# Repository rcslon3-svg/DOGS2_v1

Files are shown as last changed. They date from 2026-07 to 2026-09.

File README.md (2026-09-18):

# DOGS²

**DOGS² (Dual Output Generator Supply Station)** is an open-source, standalone
board bring-up station. It combines two programmable power outputs, current and
voltage monitoring, a signal generator, and common embedded-interface tools in
one compact instrument.

It is powered from USB Type-C or an external voltage of 5–90 V, with an output voltage of 1–48 V and a peak current of up to 5 amperes. Power anything from anything.

<p align="center">
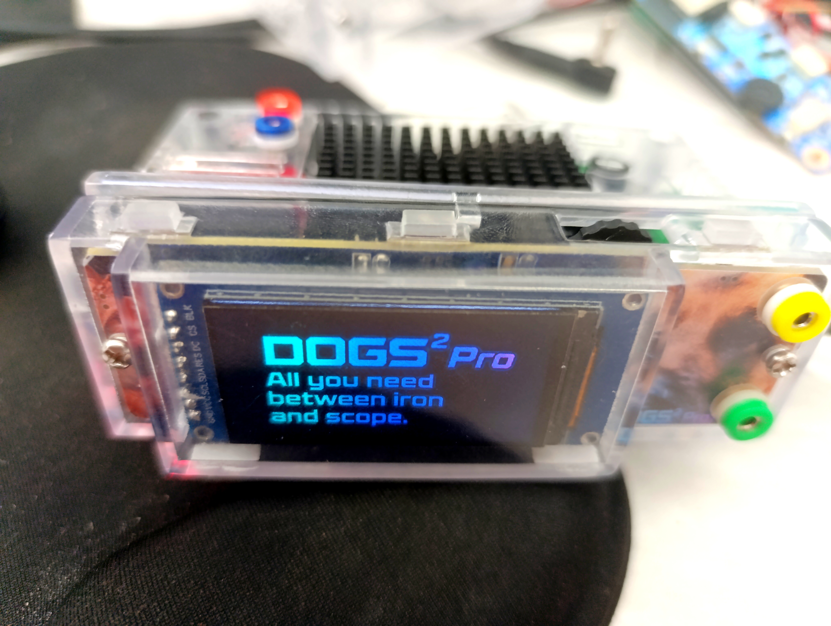
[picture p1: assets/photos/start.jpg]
DOGS² v1 welcome screen
  
</p>

<p align="center">
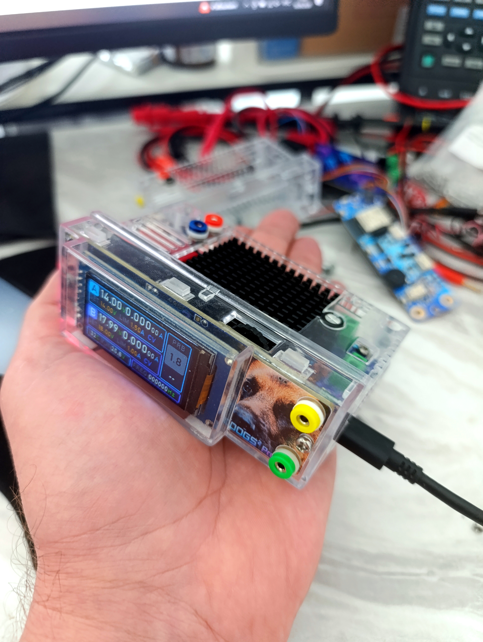
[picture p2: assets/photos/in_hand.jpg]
DOGS² v1 working engineering prototype
  
</p>

- DC/DC power channel 1-48V / 5A peak with CV/CC/OCP Shutdown operation, 50 uA current resolution;
- LDO power channel 1.3-20V / 2A peak with CV/CC/OCP Shutdown operation, 12.5 uA current resolution;
- actual values voltage and current monitoring;
- current graphics on display and phone app
- square-wave generator 1Hz - 100 kHz with 3-20V output voltage;
- UART and RS485 terminal modes;
- CAN receive, filtering, and transmission;
- LIN bus sniffer;
- I2C sniffer and I2C master terminal;
- logic probe and frequency meter input;
- standalone TFT display, encoder, and front-panel controls;
- Bluetooth SPP terminal data, command and telemetry (current graph) connection.

<p align="center">
  <strong><a href="https://dogs2.smartmoto.asia">Visit the DOGS² project website</a></strong><br>
  Project overview, beta-testing signup, and launch updates<br>
  <a href="https://hackaday.io/project/206311-dogs-dual-output-generator-supply-station">Follow the development logs on Hackaday.io</a>
</p>

This repository documents the current **v1 engineering samples**. The hardware
works and the firmware is under active development and tuning; published limits
and accuracy figures should therefore be treated as engineering-sample data,
not final product specifications.

## Project status

Five v1 engineering samples have been assembled. Hardware characterization,
firmware development, documentation, preparation for
external beta testing are ongoing.

**Want to follow or test DOGS²?** Visit the
[project website](https://dogs2.smartmoto.asia) for the overview and beta-test
signup, and follow the
[development logs on Hackaday.io](https://hackaday.io/project/206311-dogs-dual-output-generator-supply-station)
for build updates, tests, limitations, and design progress.

## Known issues the Engineering samples

Here is some known issues - read the files in directories Hardware and Mechanical.

## Repository structure

| Directory | Contents |
|---|---|
| [`hardware/`](hardware/) | Schematics, block diagram, editable design archive, PCB manufacturing files, BOMs, renders, and hardware known issues |
| [`mechanical/`](mechanical/) | Mechanical-design status and future enclosure files |
| [`software/`](software/) | Current ESP32 firmware, build configuration, tools, software documentation, and software known issues |

## Current capabilities

<p align="center">
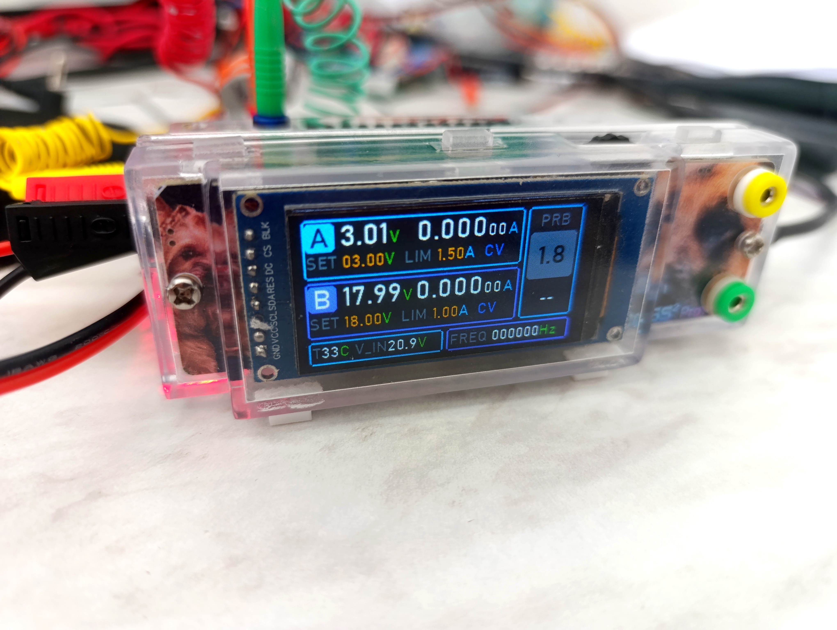
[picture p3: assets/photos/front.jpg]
DOGS² v1 connect and control
  
</p>

## Working hardware

<table>
  <tr>
    <td width="33%">
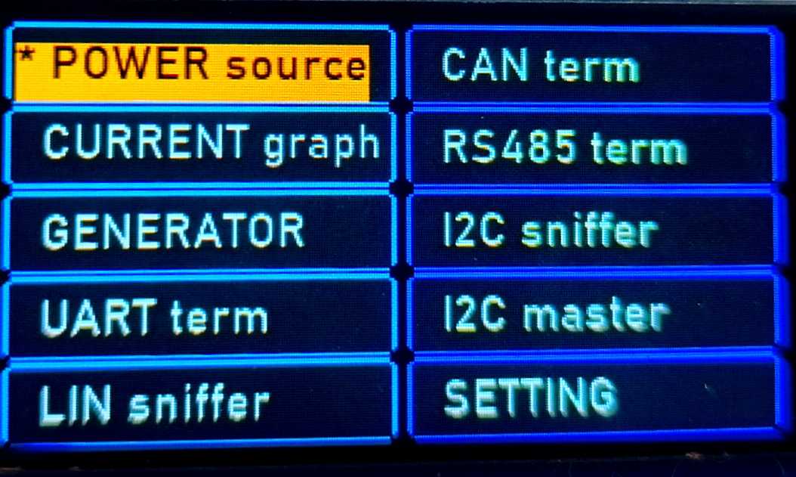
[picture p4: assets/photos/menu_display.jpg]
DOGS² v1 engineering prototype menu
      
    </td>
    <td width="33%">
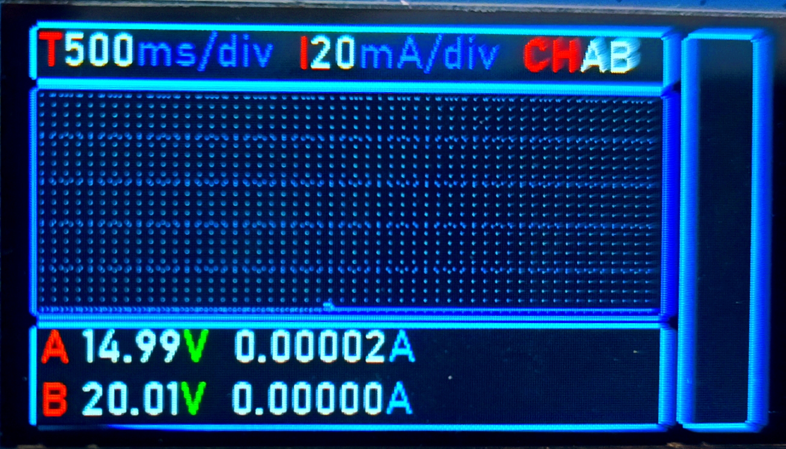
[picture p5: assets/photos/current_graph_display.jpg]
DOGS² current graph
      
    </td>
    <td width="33%">
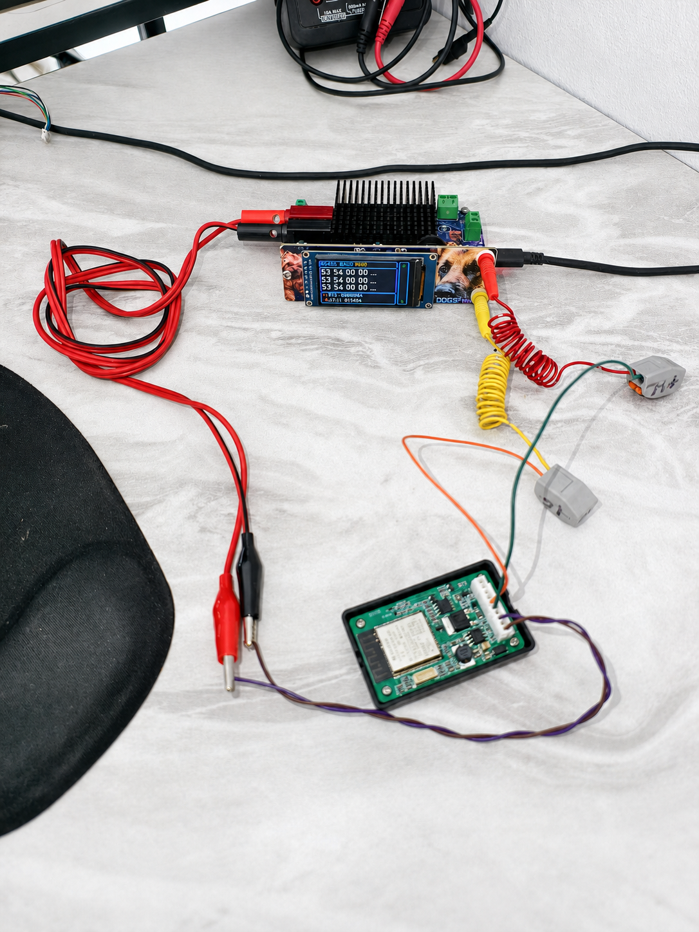
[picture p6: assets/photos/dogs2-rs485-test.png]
DOGS² during an RS485 test
      
    </td>
  </tr>
  <tr>
    <td align="center">v1 engineering prototype</td>
    <td align="center">Signal generator</td>
    <td align="center">RS485 test</td>
  </tr>
</table>

<table>
  <tr>
    <td width="25%">
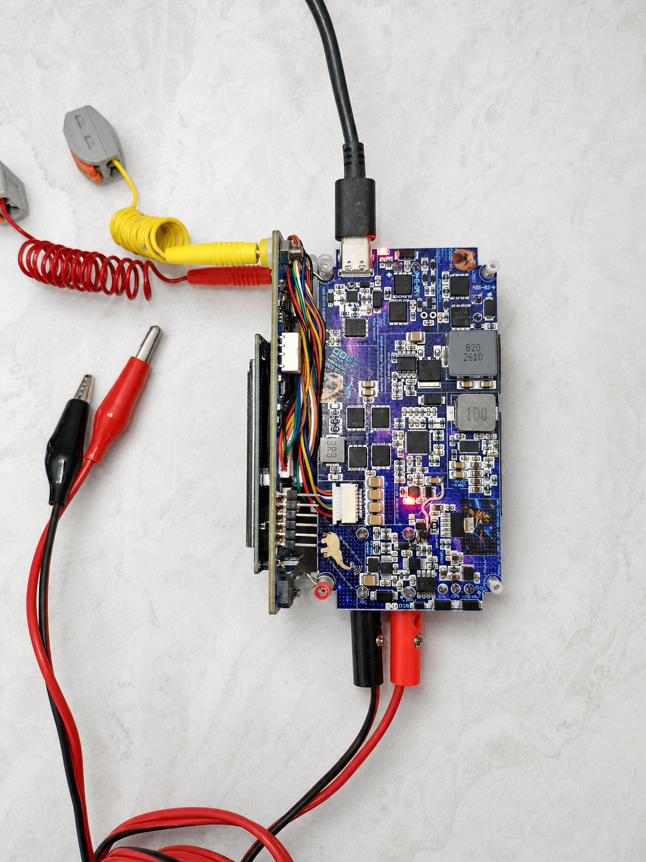
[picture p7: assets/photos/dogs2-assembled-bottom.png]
DOGS² v1 assembled prototype viewed from below
      
    </td>
    <td width="25%">
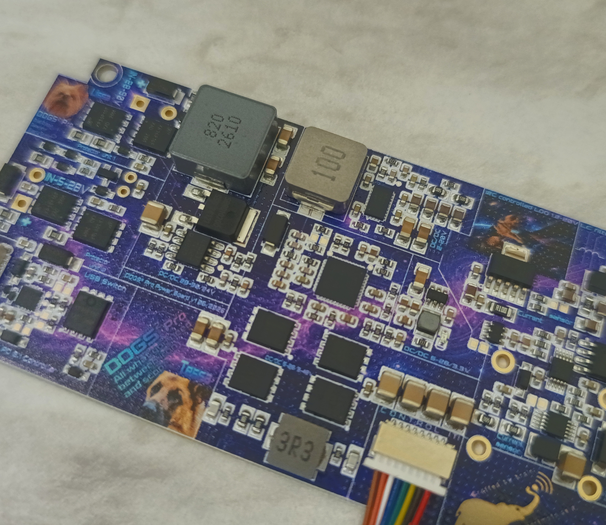
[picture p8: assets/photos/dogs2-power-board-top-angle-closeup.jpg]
DOGS² v1 power board top-angle close-up
      
    </td>
    <td width="25%">
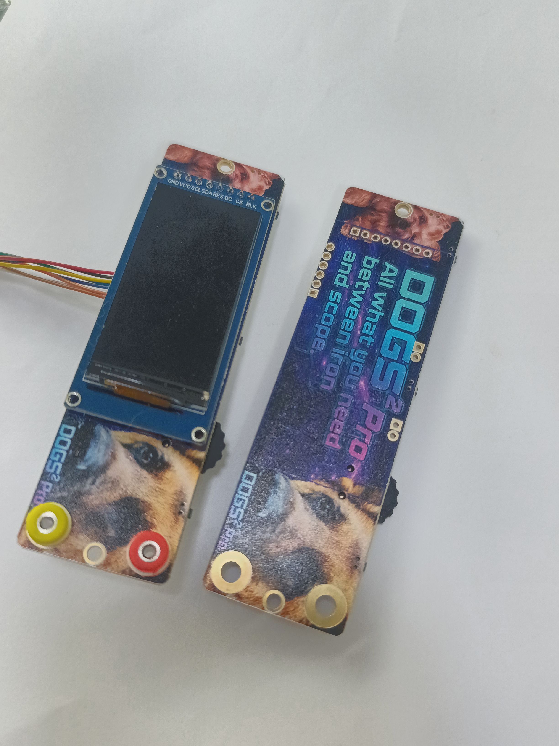
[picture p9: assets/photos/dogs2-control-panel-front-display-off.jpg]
DOGS² v1 control board front
      
    </td>
    <td width="25%">
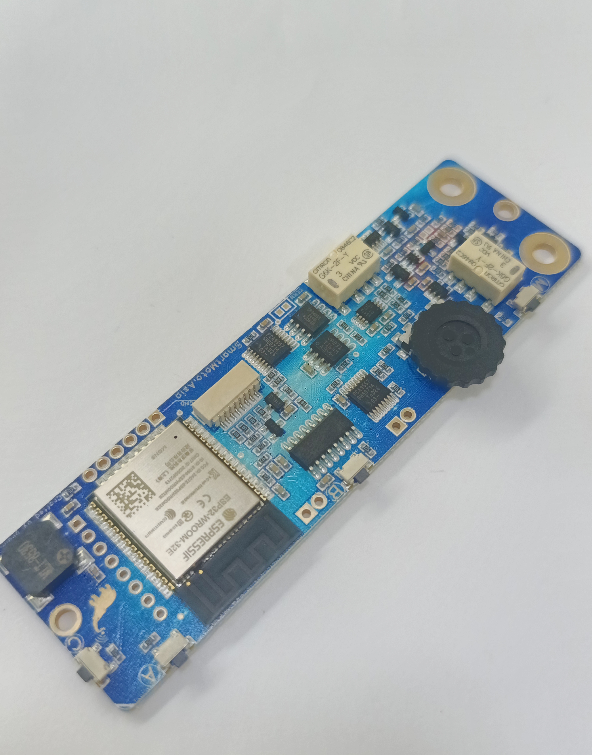
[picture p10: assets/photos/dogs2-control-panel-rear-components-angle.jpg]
DOGS² v1 control board rear
      
    </td>
  </tr>
  <tr>
    <td align="center">Assembled prototype — bottom view</td>
    <td align="center">Power board — top-angle close-up</td>
    <td align="center">Control board — front view</td>
    <td align="center">Control board — rear view</td>
  </tr>
</table>

<table>
  <tr>
    <td width="25%">
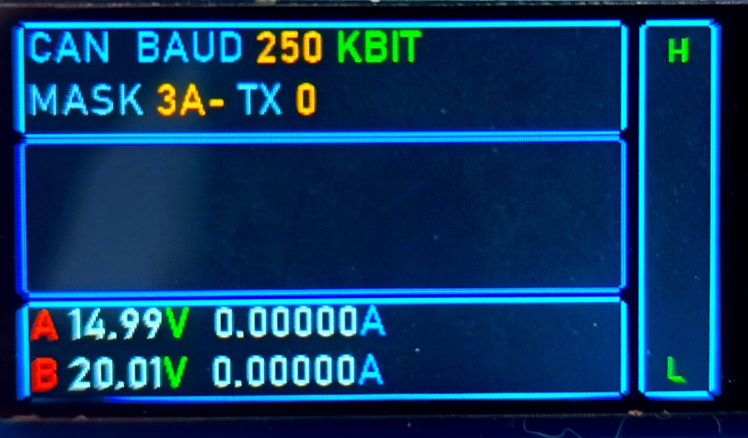
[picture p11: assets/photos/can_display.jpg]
DOGS² v1 CAN display
      
    </td>
    <td width="25%">
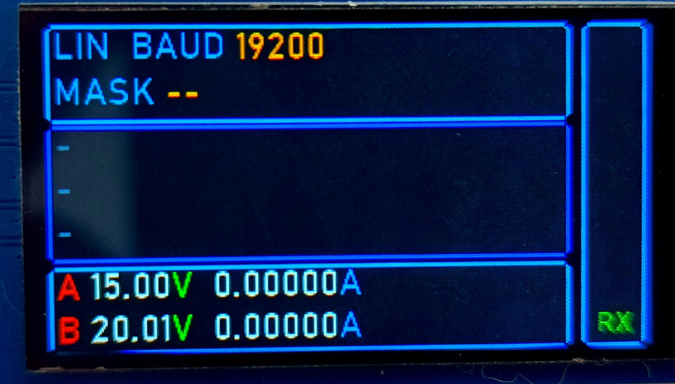
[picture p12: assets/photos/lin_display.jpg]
DOGS² v1 LIN sniffer display
      
    </td>
    <td width="25%">
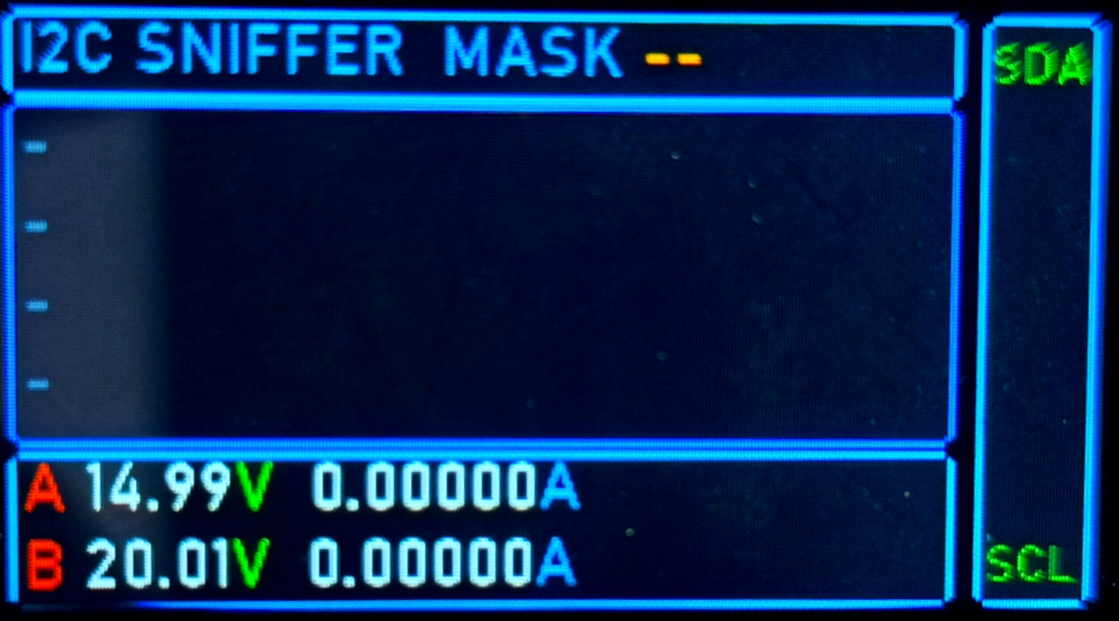
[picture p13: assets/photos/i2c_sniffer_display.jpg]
DOGS² v1 I2C sniffer display
      
    </td>
    <td width="25%">
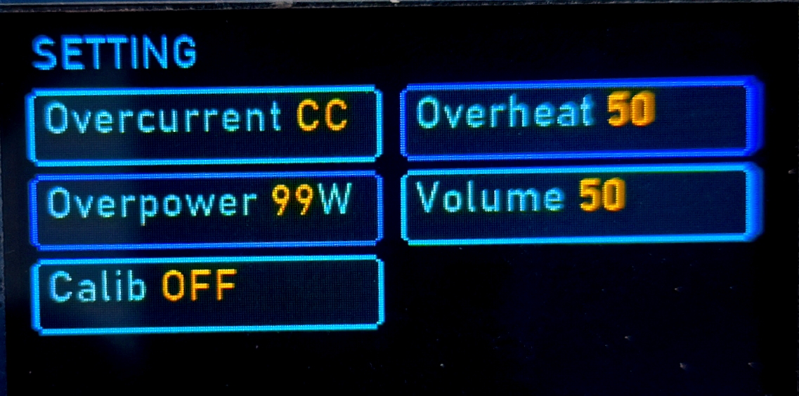
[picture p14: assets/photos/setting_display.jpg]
DOGS² v1 setting display
      
    </td>
  </tr>
  <tr>
    <td align="center">CAN display</td>
    <td align="center">LIN sniffer display</td>
    <td align="center">I2C sniffer display</td>
    <td align="center">Setting display</td>
  </tr>
</table>

## Documentation map

- Hardware overview: [`hardware/README.md`](hardware/README.md)
- Hardware schematics: [`hardware/schematic/`](hardware/schematic/)
- Firmware overview: [`software/README.md`](software/README.md)

## Licensing

The v1 hardware design is licensed under
[CERN-OHL-W-2.0](hardware/LICENSE). The firmware and software tools in
[`software/`](software/) are licensed under the
[GNU General Public License v3.0 only](software/LICENSE) (`GPL-3.0-only`).

<p align="center">
  <strong>
    <a href="https://dogs2.smartmoto.asia">Visit the DOGS² project website</a>
    ·
    <a href="https://hackaday.io/project/206311-dogs-dual-output-generator-supply-station">Follow DOGS² on Hackaday.io</a>
  </strong>
</p>

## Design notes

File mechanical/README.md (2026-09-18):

# DOGS² mechanical design

This directory contains the STEP files for the current DOGS² v1 enclosure.
The enclosure consists of one front panel, one base, and three identical
buttons.

## Known issues

Two 2.3 mm holes need to be drilled for the 2.6*16 self-tapping screws securing the top cover.
The protrusion on the lower part of the enclosure above the USB connector opening needs to be filed down in the area where it prevents the top cover from being installed.

## Enclosure parts

| File | Part | Quantity |
|---|---|---:|
| [`Front_v1_final_1.step`](Front_v1_final_1.step) | Front panel | 1 |
| [`Bottom_v1_final_1.step`](Bottom_v1_final_1.step) | Enclosure base | 1 |
| [`Top_case_v1_final_1.step`](Top_case_v1_final_1.step) | Enclosure top | 1 |
| [`Button_v1_x3_final_1.step`](Button_v1_x3_final_1.step) | Front-panel button | 3 |

## Fabricated parts

<p align="center">
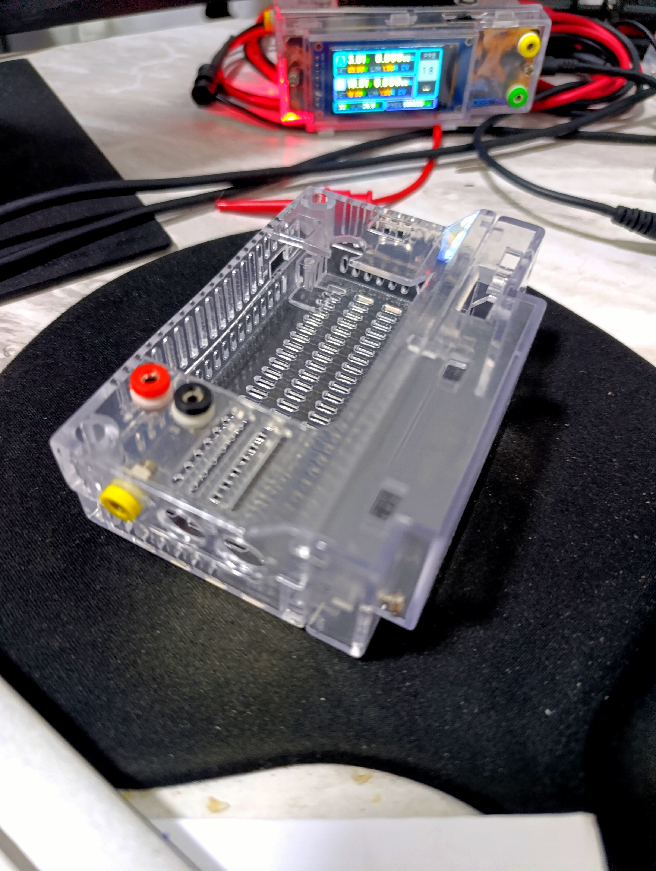
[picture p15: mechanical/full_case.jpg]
Fabricated transparent DOGS² v1 enclosure
  
</p>
<p align="center">
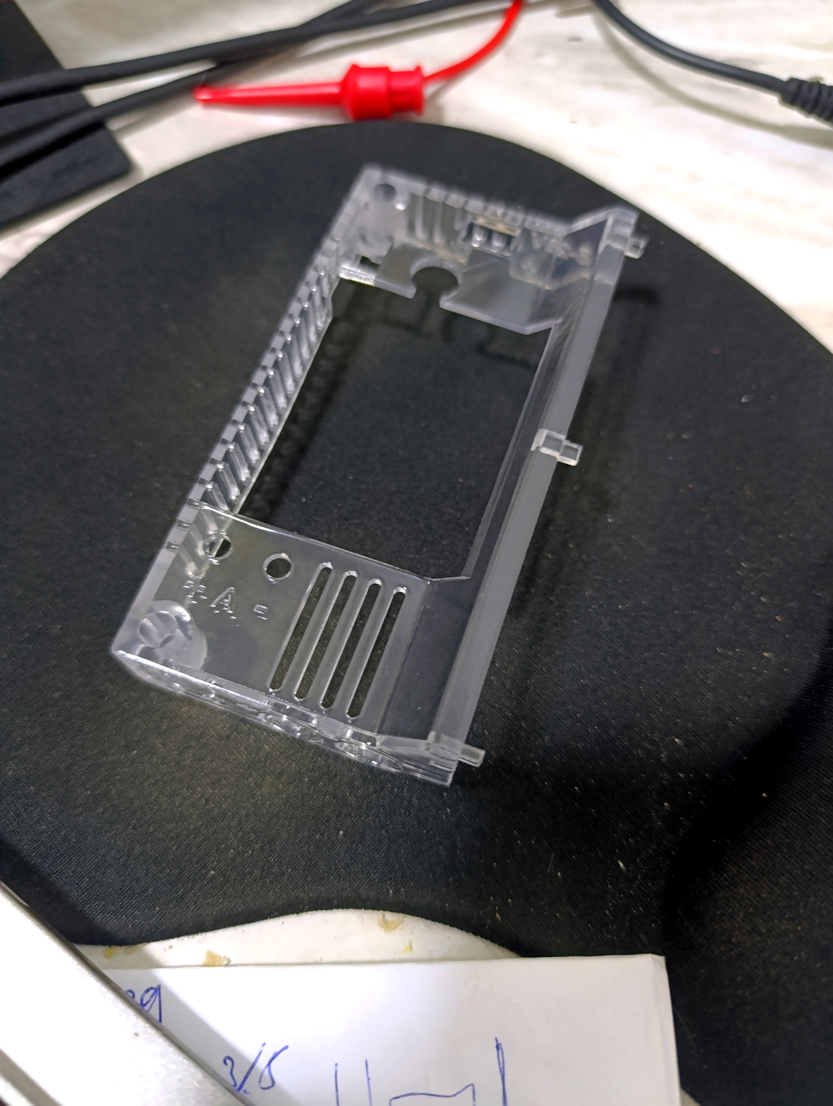
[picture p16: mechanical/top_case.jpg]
Fabricated transparent DOGS² v1 enclosure parts: top case
  
</p>
<p align="center">
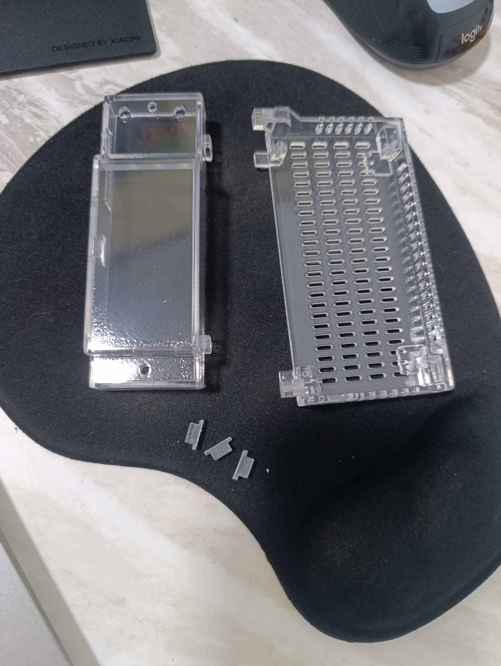
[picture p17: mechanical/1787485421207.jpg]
Fabricated transparent DOGS² v1 enclosure parts: front panel, base, and three buttons
  
</p>

These files document the enclosure fitted to the current v1 engineering
hardware. Minor mechanical refinements may still be made as testing continues.

The current hardware package and system BOM are available in
[`../hardware/`](../hardware/).

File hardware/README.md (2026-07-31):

# DOGS² v1 hardware

This directory contains the source, reference, and manufacturing files for the
current **DOGS² v1 engineering sample**.

Parameters are still being tuned and verified. The files describe the boards
that were built; they are not yet a production release.

## System architecture

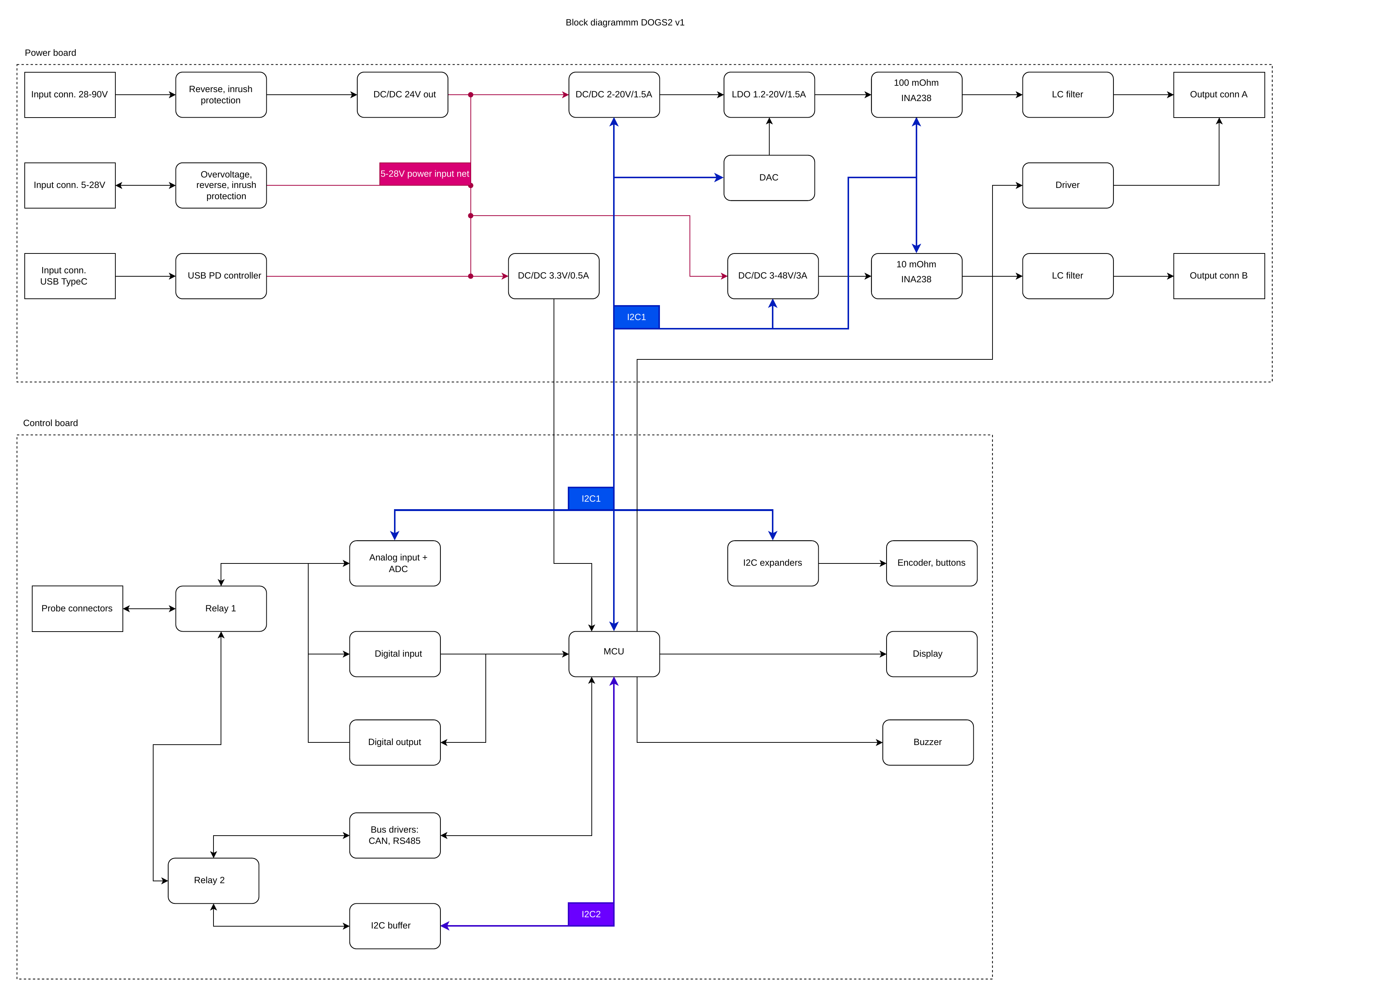
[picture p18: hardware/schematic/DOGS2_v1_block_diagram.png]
DOGS² v1 hardware block diagram


The diagram separates the power board from the control board and shows the
power paths, two programmable outputs, measurements, processor, controls, probe
connections, and digital-interface drivers.

- [View the block diagram as PDF](schematic/DOGS2_v1_block_diagram.pdf)
- [View the complete schematic](schematic/DOGS2_v1_schematic.pdf)

## Board renders

<table>
  <tr>
    <td width="50%">
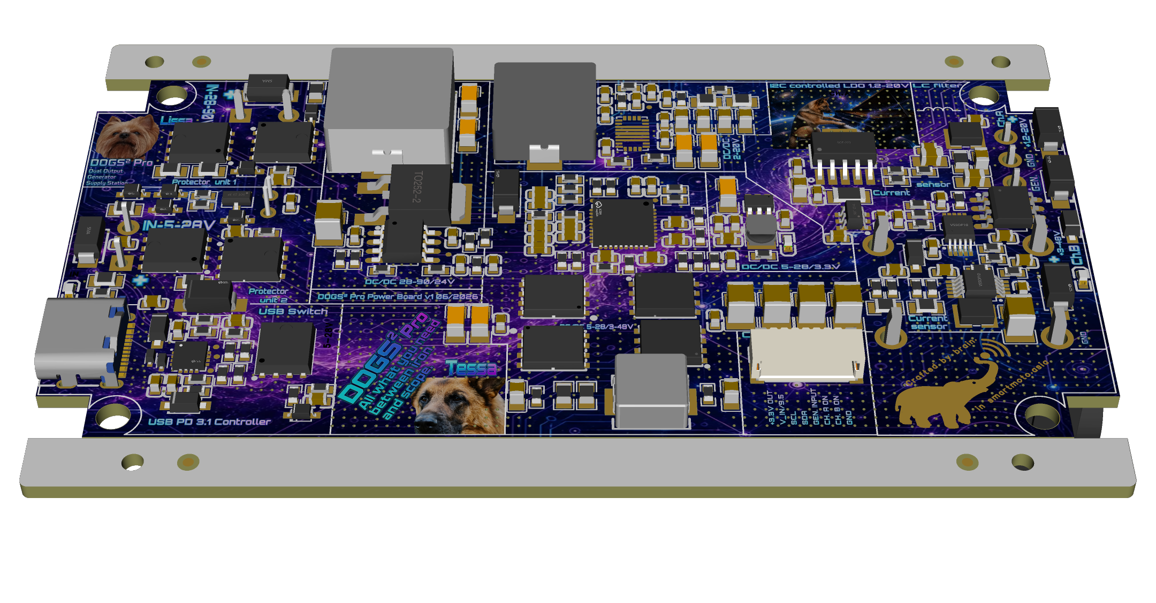
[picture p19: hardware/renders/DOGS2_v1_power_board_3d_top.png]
DOGS² v1 power board render
      
    </td>
    <td width="50%">
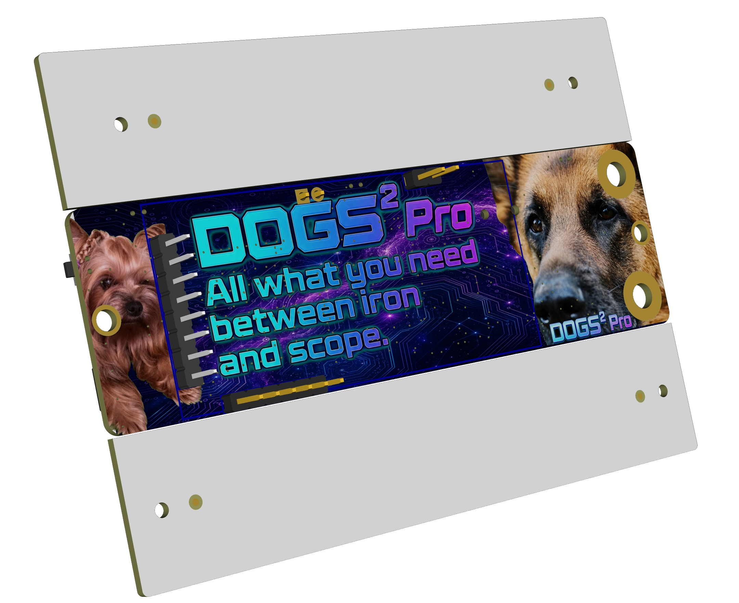
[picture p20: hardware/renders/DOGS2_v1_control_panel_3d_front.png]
DOGS² v1 control panel render
      
    </td>
  </tr>
  <tr>
    <td align="center">Power board render</td>
    <td align="center">Control panel render</td>
  </tr>
  <tr>
    <td width="50%">
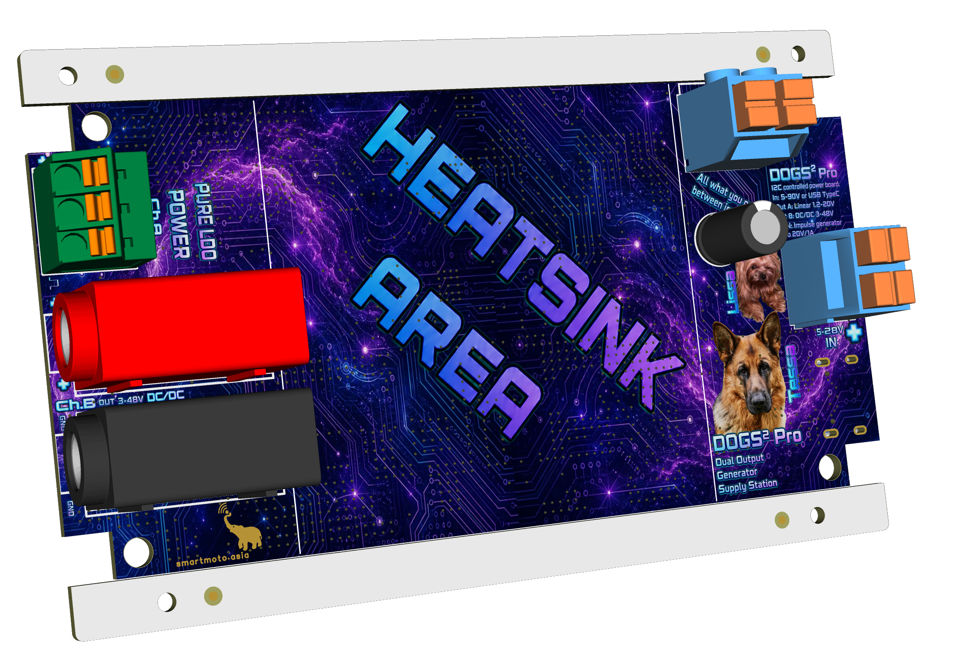
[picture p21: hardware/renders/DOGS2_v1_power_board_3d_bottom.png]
DOGS² v1 power board bottom render
      
    </td>
    <td width="50%">
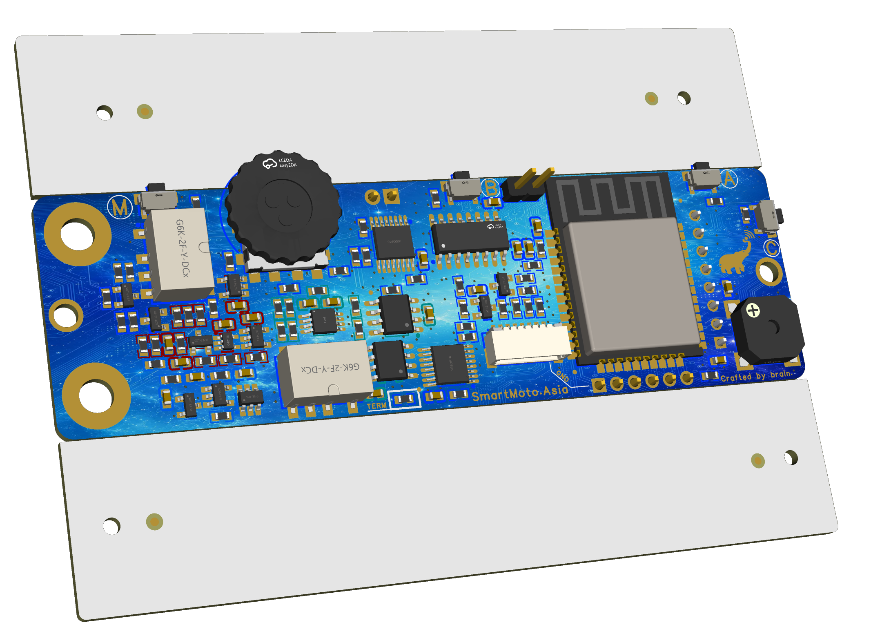
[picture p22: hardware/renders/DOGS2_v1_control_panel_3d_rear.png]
DOGS² v1 control panel rear render
      
    </td>
  </tr>
  <tr>
    <td align="center">Power board — bottom</td>
    <td align="center">Control panel — rear</td>
  </tr>
</table>

## Directory contents

### `design/`

| File | Purpose |
|---|---|
| `DOGS2_v1_easyeda_project.zip` | Complete editable EasyEDA project archive |

### `schematic/`

| File | Purpose |
|---|---|
| `DOGS2_v1_block_diagram.pdf` | Publication-quality system block diagram |
| `DOGS2_v1_block_diagram.png` | GitHub preview generated from the block-diagram PDF |
| `DOGS2_v1_schematic.pdf` | Power-board and control-panel schematics |

### `manufacturing/`

- `control_panel/`: Gerbers, BOM, and pick-and-place data for the control panel.
- `power_board/`: Gerbers, BOM, and pick-and-place data for the power board.
- `DOGS2_v1_system_bom.xlsx`: system-level BOM for boards, display, enclosure
  parts, and purchased items.

### `renders/`

Top/bottom power-board and front/rear control-panel renders.

## Revision and manufacture

All files in this directory belong to hardware revision **v1**. Before ordering
boards, read [`KNOWN_ISSUES.md`](KNOWN_ISSUES.md). Manufacturing parameters
have intentionally not been prescribed here: use the requirements contained in
the Gerber packages and confirm them with the chosen PCB assembler.

## License

The DOGS² v1 hardware design files are licensed under the
**CERN Open Hardware Licence Version 2 - Weakly Reciprocal
(CERN-OHL-W-2.0)**. See [`LICENSE`](LICENSE).

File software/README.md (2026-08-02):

# DOGS² firmware

This directory contains the current firmware for the DOGS² v1 engineering
sample. It targets an ESP32-WROOM module and uses ESP-IDF through PlatformIO.

## Implemented modes

| Display mode | Current implementation |
|---|---|
| Power Source | Two output setpoints, output enable, CV/CC status, voltage/current monitoring, input voltage, temperature, and frequency |
| Generator | Square-wave frequency, duty cycle, and output control |
| UART | Configurable serial terminal with Bluetooth forwarding |
| LIN | Configurable serial receive path and filter UI; full LIN decoder is in development |
| 1-Wire | UI placeholder; decoder is in development |
| RS485 | Configurable half-duplex terminal |
| CAN | Configurable bitrate and filter, receive display, Bluetooth reporting, and frame transmission |
| I2C Sniffer | Passive capture with address filter |
| I2C Master | 100 kHz scan, register/raw read, and register/raw write commands |
| Settings | Protection thresholds and user settings |

Bluetooth SPP exposes commands and telemetry without consuming another USB
port. The default device name is `DOGS2_A001`.

## Build

Install [PlatformIO](https://platformio.org/), open this directory as the
project root, and run:

```text
pio run
```

The default environment is `logic_v2_engineering_sample`. The latest committed
firmware was build-tested with this environment before the repository
reorganization.

## Layout

| Path | Purpose |
|---|---|
| `include/` | Public module headers and board configuration |
| `src/` | ESP-IDF application and drivers |
| `tools/` | Font and splash-image generation helpers |
| `assets/` | Source/preview artwork used by the firmware |
| `docs/` | Focused implementation notes and terminal command reference |

Start with [`docs/MEASUREMENT_MODES.md`](docs/MEASUREMENT_MODES.md) for a
high-level map of the running firmware.

## License

The firmware and software tools in this directory are licensed under the
[GNU General Public License v3.0 only](LICENSE) (`GPL-3.0-only`).

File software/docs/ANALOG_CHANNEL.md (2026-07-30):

# Analog input

The current firmware reads the DOGS² v1 engineering-sample analog path through
the ESP32 ADC on GPIO36. The board-specific divider is selected at compile time
by `LOGIC_V2_BOARD_REV`.

For the engineering sample, the divider model in `include/probe_config.h` uses:

```text
VIN = VADC × 11.87234
```

The channel reports measured input voltage and classifies the probe state using
the current firmware thresholds:

```text
LOW          ≤ 0.8 V
HIGH         ≥ 2.6 V
OVERVOLTAGE  ≥ 15 V
```

Intermediate readings are reported as undefined/high-impedance according to
the active measurement state. ADC sampling, averaging, display hysteresis, and
the exact thresholds are defined in `include/probe_config.h`; that file is the
source of truth while calibration continues.

The old document described a temporary Logic_v1/CYD resistor network and
GPIO27 injection test. That wiring does not describe the current v1
engineering sample and has been removed from this documentation.

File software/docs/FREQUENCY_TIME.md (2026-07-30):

# Frequency input

The DOGS² v1 engineering sample has a dedicated frequency input on GPIO13.
The firmware uses the ESP32 pulse counter to count rising edges in a timed
window and calculates:

```text
frequency = edge count / elapsed time
```

The displayed value is cleared after the configured no-signal timeout. The
current implementation intentionally does **not** claim pulse-width, polarity,
edge-event, or duty-cycle measurement on this input.

Relevant implementation:

- `src/timing_input.c`
- `include/probe_config.h`
- `FREQUENCY_INPUT_GPIO`
- `SIGNAL_MISSING_MS`

The separate generator mode has its own adjustable frequency and duty cycle;
those output settings are not measurements made by this input.

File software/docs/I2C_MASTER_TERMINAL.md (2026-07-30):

# DOGS² I²C Master Terminal

## Назначение

Модуль позволяет использовать DOGS² как I²C master и управлять внешними
I2C-устройствами из Bluetooth-терминала:

- искать устройства на шине;
- читать регистры;
- записывать регистры;
- выполнять чтение и запись без байта адреса регистра.

Режим работает на второй аппаратной I2C-шине ESP32.

| Параметр | Значение |
|---|---|
| Контроллер | `I2C_NUM_1` |
| SCL | GPIO26 |
| SDA | GPIO27 |
| Частота чтения и записи | 100 кГц |
| Уровень | 3,3 В |
| Адреса | 7-битные |

SCL и SDA должны иметь внешние pull-up резисторы к 3,3 В. Линии нельзя
подтягивать к 5 В.

## Файлы

- `src/i2c_master_terminal.c` — Bluetooth-команды, разбор строк, ответы и
  строки для дисплея.
- `include/i2c_master_terminal.h` — интерфейс terminal-модуля.
- `src/i2c_aux_bus.c` — владение I2C_NUM_1, scan, транзакции и recovery.
- `include/i2c_aux_bus.h` — интерфейс шины.

## Жизненный цикл

I2C_NUM_1 существует только в режиме `APP_MODE_I2C_MASTER`.

При входе в режим модуль:

1. захватывает GPIO26 и GPIO27;
2. создаёт `i2c_master_bus_handle_t`;
3. начинает принимать Bluetooth-команды.

При выходе из режима модуль:

1. запрещает приём новых I2C-команд;
2. очищает очередь и незавершённую строку;
3. дожидается окончания текущей короткой транзакции;
4. удаляет `i2c_master_bus_handle_t`;
5. возвращает GPIO26 и GPIO27 в режим входов.

Все операции с handle защищены одним mutex. Создание, удаление, recovery,
чтение и запись не могут выполняться одновременно.

## Ввод команд

Команда завершается одним из способов:

- символом `CR`;
- символом `LF`;
- паузой ввода не менее 200 мс.

Регистр и данные задаются шестнадцатеричными числами без `0x`. Регистр `0A`
означает десятичное значение 10. Параметр `len` задаётся десятичным числом.

Максимальный объём данных одной команды — 32 байта.

Разделителями могут быть пробелы, табуляция и запятые. Имена команд и
шестнадцатеричные цифры нечувствительны к регистру.

## Команды

### Поиск устройств

```text
S
```

Проверяются 7-битные адреса `0x03`–`0x77`. Для каждого адреса формируется
только address frame:

```text
START → address + W → ACK/NACK → STOP
```

Пример ответа:

```text
[I2C] SCAN: 41 44
```

Если ни одно устройство не ответило:

```text
[I2C] SCAN: NONE
```

Scan выполняется программно через open-drain GPIO. На время scan аппаратный
I2C-контроллер отсоединяется, после завершения создаётся заново. Такой scan
используется потому, что `i2c_master_probe()` в применяемой версии ESP-IDF
может неограниченно ожидать освобождения BUSY после NACK.

Каждый адрес проверяется один раз. Одиночный ACK означает найденное
устройство.

### Чтение регистра

```text
R <addr> <reg> <len>
```

Модуль выполняет одну combined-транзакцию:

```text
START
address + W
reg
REPEATED START
address + R
len байтов
STOP
```

`len` — количество байтов, а не количество регистров.

Пример чтения двух байтов регистра `0x01` устройства `0x41`:

```text
R 41 01 2
```

Ответ:

```text
[I2C] R 41 01: FB 68 OK
```

Команда не знает ширину регистра конкретного устройства. Запрашивать нужно
ровно столько байтов, сколько определено документацией микросхемы.

### Запись регистра

```text
W <addr> <reg> <data...>
```

На шину передаётся один пакет:

```text
START → address + W → reg → data... → STOP
```

Пример записи `0x12AB` в регистр `0x02` устройства `0x41`:

```text
W 41 02 12 AB
```

Ответ:

```text
[I2C] W 41 02 12 AB OK
```

Порядок байтов задаёт пользователь. Для 16-битного big-endian регистра
сначала передаётся старший байт.

### Чтение без адреса регистра

```text
RR <addr> <len>
```

Выполняется обычное чтение `len` байтов без предварительной записи register
pointer:

```text
START → address + R → data... → STOP
```

Команда нужна для устройств без регистров, FIFO и устройств, которые сохраняют
внутренний register pointer.

Пример:

```text
RR 50 8
```

### Запись без адреса регистра

```text
WW <addr> <data...>
```

Все указанные байты передаются без автоматически добавляемого регистра:

```text
START → address + W → data... → STOP
```

Пример:

```text
WW 3C 00 AF
```

## Пример: INA238

INA238 по адресу `0x41` имеет преимущественно 16-битные регистры. Их нужно
читать по два байта:

```text
R 41 00 2
R 41 01 2
R 41 02 2
```

Типичные ответы после сброса:

```text
[I2C] R 41 00: 00 00 OK
[I2C] R 41 01: FB 68 OK
```

Запрос:

```text
R 41 00 3
```

не означает чтение регистров `0x00`, `0x01` и `0x02`. Он запрашивает три
байта из одной транзакции, начатой с register pointer `0x00`. Для
16-битного регистра `0x00` INA238 определены только первые два байта;
значение третьего байта использовать нельзя.

Исключение — 24-битный регистр `POWER` по адресу `0x08`:

```text
R 41 08 3
```

Для чтения нескольких регистров необходимо отправить отдельную команду `R`
для каждого register pointer.

## Ответы и ошибки

Все ответы имеют префикс `[I2C]`.

| Ответ | Значение |
|---|---|
| `OK` | Транзакция завершена |
| `SCAN: NONE` | На адресах `0x03`–`0x77` нет ACK |
| `NACK_ADDR` | Устройство не подтвердило адрес |
| `TIMEOUT` | Транзакция не завершилась за заданное время или SCL удерживается низким |
| `ERR syntax` | Ошибка формата команды или диапазона параметра |
| `MASTER START ERR` | Не удалось захватить GPIO или создать I2C_NUM_1 |

После timeout модуль выполняет физическое восстановление шины:

1. удаляет аппаратный I2C bus;
2. освобождает SDA;
3. выдаёт до девяти импульсов SCL;
4. формирует STOP;
5. заново создаёт I2C_NUM_1.

Если SCL удерживается внешним устройством низким, recovery завершается
ошибкой по ограниченному timeout и не зависает бесконечно.

## Ограничения

- Поддерживаются только 7-битные адреса.
- `reg` имеет размер один байт.
- `len` находится в диапазоне 1–32 байта.
- Terminal не знает карту и ширину регистров подключённого устройства.
- Автоматического чтения последовательных register pointer нет.
- PEC/CRC автоматически не добавляется и не проверяется.
- Режим не предназначен для подключения к активной multi-master шине.
- При выходе из I2C Master текущая последовательность команд отменяется.

## Программный интерфейс

`i2c_master_terminal` вызывается из приложения:

```c
i2c_master_terminal_init();
i2c_master_terminal_configure(mode);
i2c_master_terminal_input_char(ch);
i2c_master_terminal_update(state);
```

`i2c_aux_bus` предоставляет операции:

```c
i2c_aux_bus_init();
i2c_aux_bus_start();
i2c_aux_bus_stop();
i2c_aux_bus_scan(...);
i2c_aux_bus_transmit_receive(...);
i2c_aux_bus_receive(...);
i2c_aux_bus_transmit(...);
i2c_aux_bus_recover_lines();
i2c_aux_bus_reset_controller();
```

Вызывать аппаратные функции I2C_NUM_1 напрямую из других модулей не следует.
Владельцем handle и GPIO является `i2c_aux_bus`.

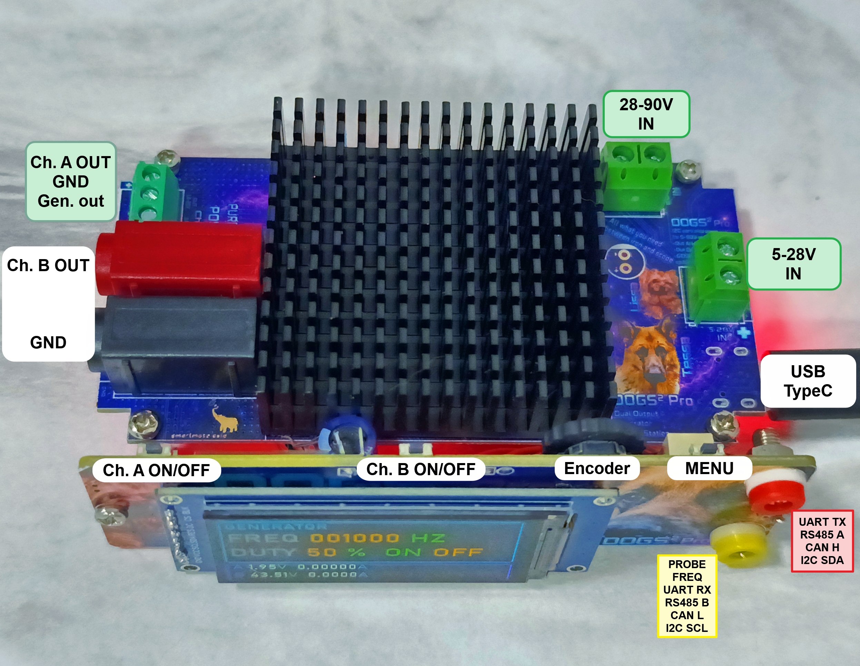
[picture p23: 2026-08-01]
assets/photos/pinout.jpg

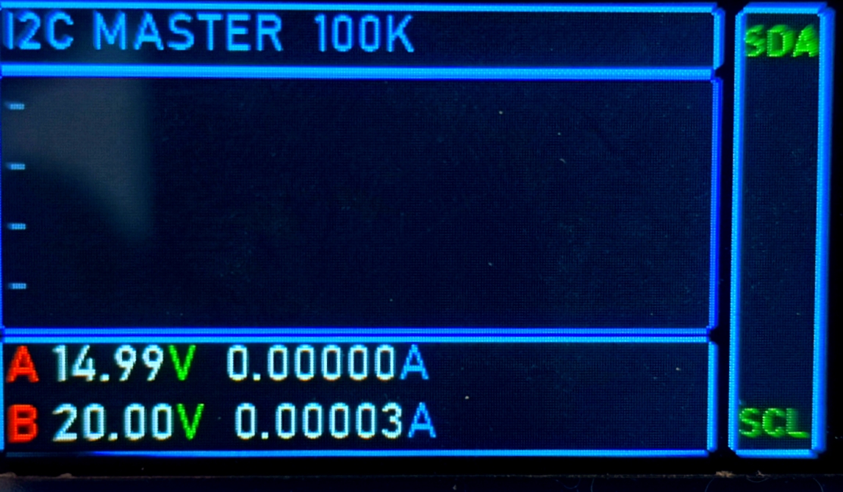
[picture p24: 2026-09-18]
assets/photos/i2c_master_display.jpg

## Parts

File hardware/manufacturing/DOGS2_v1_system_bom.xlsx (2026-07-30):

Номер | Наименование | К-во | Цена | Ссылка
1 | Шлейф 8 pin SH 1.0 | 1 | 47.00 | https://www.lazada.co.th/products/i5646502004-s24059791432.html
2 | Радиатор 50 50 | 1 | 48.00 | https://www.lazada.co.th/products/i4522716056-s22979981043.html
3 | Термопрокладка 0.5 | 1 | 30.00 | https://www.lazada.co.th/products/i2550527994-s9072522788.html
4 | Клемма 2 pin шаг 5 | 2 | 8.00 | https://www.lazada.co.th/products/i6060999849-s26298752211.html
5 | Клемма 3 pin шаг 3.5 | 1 | 5.50 | https://www.lazada.co.th/products/i16183971310-s127280994510.html
6 | Клемма банан 4мм PCB черн + красн | 2 | 24.00 | https://www.lazada.co.th/products/i16158955402-s127159279003.html
7 | Клемма банан 2мм в отверстие красн+желт | 2 | 7.00 | https://www.lazada.co.th/products/i6075798343-s26449366257.html
8 | Дисплей 1.9 Inch IPS Full Angle TFT Display Screen LCD Screen Color Display Module SPI Serial Port High-definition 170x320 ST7789 | 1 | 90.00 | https://th.aliexpress.com/item/1005008295027783.html
9 | Штырь банан 2мм желтый+красн | 2 | 15.00 | https://www.lazada.co.th/products/i6075798343-s26449366257.html
10 | Собранная плата Power board | 1
11 | Собранная плата Control board | 1
12 | Нижняя часть корпуса | 1
13 | Верхняя часть корпуса | 1
14 | Крепежные винты для плат и корпуса | TBD

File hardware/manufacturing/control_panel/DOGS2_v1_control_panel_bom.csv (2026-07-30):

No. | Quantity | Comment | Designator | Footprint | Value | Manufacturer Part | Manufacturer | Supplier Part | Supplier
1 | 1 | 2.7kHz | BUZZER1 | BUZ-SMD_4P-L8.5-W8.5-P8.50-BR | 2.7kHz | MLT-8530 | 华能 | C94599 | LCSC
2 | 20 | 47nF | C1,C2,C3,C4,C5,C6,C7,C8,C9,C10,C11,C12,C13,C14,C15,C16,C19,C20,C21,C22 | C0603 | 47nF | CL10B473KB8NNNC | SAMSUNG(三星) | C1622 | LCSC
3 | 2 | BAV99 | D2,D3 | SOT-23-3_L2.9-W1.3-P1.90-LS2.4-BR |  | BAV99 | R+O(宏嘉诚) | C7420336 | LCSC
4 | 2 | SM712 | D6,D10 | SOT-23_L2.9-W1.3-P1.90-LS2.4-BR |  | SM712 | DOWO(东沃) | C293966 | LCSC
5 | 1 | PESD2CAN | D7 | SOT-23-3_L2.9-W1.3-P1.90-LS2.4-BR |  | PESD2CAN | DOWO(东沃) | C284078 | LCSC
6 | 2 | G6K-2F-Y DC3 | K3,K4 | RELAY-SMD_G6K-2F-Y |  | G6K-2F-Y DC3 | OMRON(欧姆龙) | C93168 | LCSC
7 | 1 | AO3401A | Q1 | SOT-23_L2.9-W1.3-P1.90-LS2.4-BR |  | AO3401A | AOS | C15127 | LCSC
8 | 9 | 47kΩ | R1,R17,R18,R20,R21,R22,R28,R33,R42 | R0603 | 47kΩ | 0603WAF4702T5E | UNI-ROYAL(厚声) | C25819 | LCSC
9 | 19 | 4.7kΩ | R2,R3,R4,R5,R6,R7,R8,R12,R24,R25,R26,R27,R34,R35,R36,R37,R38,R40,R43 | R0603 | 4.7kΩ | 0603WAF4701T5E | UNI-ROYAL(厚声) | C23162 | LCSC
10 | 11 | 1kΩ | R9,R10,R11,R14,R15,R16,R19,R23,R32,R39,R41 | R0603 | 1kΩ | 0603WAF1001T5E | UNI-ROYAL(厚声) | C21190 | LCSC
11 | 2 | 330kΩ | R29,R31 | R0603 | 330kΩ | 0603WAF3303T5E | UNI-ROYAL(厚声) | C23137 | LCSC
12 | 11 | 10Ω | R30,R44,R45,R46,R49,R50,R52,R53,R54,R55,R56 | R0603 | 10Ω | 0603WAF100JT5E | UNI-ROYAL(厚声) | C22859 | LCSC
13 | 4 | TS24CA | SW1,SW2,SW3,SW4 | SW-SMD_2P-TS24CA |  | TS24CA | SHOU HAN(首韩) | C393942 | LCSC
14 | 1 | SIQ-02FVS3 | U1 | SW-SMD_SIQ-02FVS3_1 |  | SIQ-02FVS3 | MITSUMI(美上美) | C2925423 | LCSC
15 | 1 | ULN2003LVDRG | U2 | SOIC-16_L9.9-W3.9-P1.27-LS6.0-BL |  | ULN2003LVDRG | HGC(深圳汉芯) | C19723745 | LCSC
16 | 1 | PCA9517ADP,118 | U3 | TSSOP-8_L3.0-W3.0-P0.65-LS4.9-BL |  | PCA9517ADP,118 | NXP(恩智浦) | C80799 | LCSC
17 | 1 | ZX-SH1.0-8PWT | U5 | CONN-SMD_8P-P1.00_MEGASTAR_ZX-SH1.0-8PWT |  | ZX-SH1.0-8PWT | Megastar(兆星) | C7430450 | LCSC
18 | 1 | 2.4GHz | U8 | WIFI-SMD_ESP32-WROOM-32E | 2.4GHz | ESP32-WROOM-32E-N8 | ESPRESSIF(乐鑫) | C701342 | LCSC
19 | 2 | PCA9557PW,118 | U17,U28 | TSSOP-16_L5.0-W4.4-P0.65-LS6.4-BL |  | PCA9557PW,118 | NXP(恩智浦) | C141380 | LCSC
20 | 1 | ADS1110A0IDBVR | U20 | SOT-23-6_L2.9-W1.6-P0.95-LS2.8-BR |  | ADS1110A0IDBVR | TI(德州仪器) | C16598 | LCSC
21 | 2 | SN74LVC1G126DBVR(AT) | U21,U24 | SOT-23-5_L3.0-W1.7-P0.95-LS2.8-BR |  | SN74LVC1G126DBVR(AT) | AOTE(奥特) | C55089945 | LCSC
22 | 1 | LMV331IDCKR | U22 | SC-70-5_L2.1-W1.3-P0.65-LS2.1-BR |  | LMV331IDCKR | TI(德州仪器) | C7976 | LCSC
23 | 1 | MCP6001T-I/OT | U23 | SOT-23-5_L3.0-W1.7-P0.95-LS2.8-BR |  | MCP6001T-I/OT | MICROCHIP(美国微芯) | C116490 | LCSC
24 | 1 | SN65HVD231DR | U25 | SOIC-8_L4.9-W3.9-P1.27-LS6.0-BL |  | SN65HVD231DR | TI(德州仪器) | C129257 | LCSC
25 | 1 | SP3485EN-L/TR | U26 | SOIC-8_L5.0-W4.0-P1.27-LS6.0-BL |  | SP3485EN-L/TR | MaxLinear(迈凌) | C8963 | LCSC

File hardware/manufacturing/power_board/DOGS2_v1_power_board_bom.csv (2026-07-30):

No. | Quantity | Comment | Designator | Footprint | Value | Manufacturer Part | Manufacturer | Supplier Part | Supplier
1 | 7 | 100pF | C1,C10,C15,C35,C55,C56,C62 | C0603 | 100pF | CL10C101JB8NNNC | SAMSUNG(三星) | C14858 | LCSC
2 | 8 | 10uF | C2,C5,C9,C25,C26,C27,C28,C59 | C0805 | 10uF | GRM21BR61H106KE43L | muRata(村田) | C440198 | LCSC
3 | 32 | 100nF | C3,C7,C12,C14,C20,C21,C22,C30,C31,C33,C38,C45,C57,C69,C71,C72,C73,C74,C76,C77,C78,C79,C80,C81,C82,C83,C84,C85,C86,C87,C88,C89 | C0603 | 100nF | CL10B104KC8NNNC | SAMSUNG(三星) | C15725 | LCSC
4 | 8 | 10uF | C4,C17,C32,C37,C41,C50,C52,C53 | C0603 | 10uF | CL10A106MA8NRNC | SAMSUNG(三星) | C96446 | LCSC
5 | 3 | 2.2nF | C6,C8,C29 | C0603 | 2.2nF | 0603B222K500NT | FH(风华) | C1604 | LCSC
6 | 4 | 4.7nF | C11,C13,C34,C65 | C0603 | 4.7nF | 0603B472K500NT | FH(风华) | C53987 | LCSC
7 | 7 | 10uF | C16,C18,C23,C24,C39,C40,C58 | C1206 | 10uF | CL31A106KBHNNNE | SAMSUNG(三星) | C13585 | LCSC
8 | 6 | 10uF | C19,C44,C46,C47,C48,C49 | C1210 | 10uF | FS32X106K101EGG | PSA(信昌电陶) | C5156756 | LCSC
9 | 2 | 680pF | C42,C43 | C0805 | 680pF | CC0805JRNPO0BN681 | YAGEO(国巨) | C513601 | LCSC
10 | 2 | XY118-5.0-2P | CN1,CN6 | CONN-TH_XY118-5.0-2P |  | XY118-5.0-2P | XINLAIYA(新莱亚) | C784922 | LCSC
11 | 1 | 24.243.2 | CN3 | CONN-TH_24.243.2 |  | 24.243.2 | AMASS(艾迈斯) | C7437322 | LCSC
12 | 1 | KF250NH-3.5-3P | CN4 | CONN-TH_KF250NH-3.5-3P |  | KF250NH-3.5-3P | KEFA(科发) | C976557 | LCSC
13 | 1 | 24.243.1 | CN5 | CONN-TH_24.243.1_RED |  | 24.243.1 | AMASS(艾迈斯) | C7437321 | LCSC
14 | 1 | SBRD10200 | D1 | TO-252-2_L6.6-W6.1-P4.57-LS9.9-BR-CW |  | SBRD10200 | SMC(桑德斯) | C3759040 | LCSC
15 | 2 | H5VUD5BB | D2,D3 | SOD-523_L1.2-W0.8-LS1.6-BI |  | H5VUD5BB | R+O(宏嘉诚) | C20615820 | LCSC
16 | 2 | SMAJ90CA | D4,D5 | SMA_L4.4-W2.6-LS5.0-BI |  | SMAJ90CA | R+O(宏嘉诚) | C42394402 | LCSC
17 | 4 | SMAJ28A | D6,D15,D16,D17 | SMA_L4.3-W2.6-LS5.0-RD |  | SMAJ28A | R+O(宏嘉诚) | C19077545 | LCSC
18 | 4 | 1N4148W | D7,D8,D9,D10 | SOD-123F_L2.7-W1.6-LS3.8-RD |  | 1N4148W | ST(先科) | C81598 | LCSC
19 | 1 | SMAJ90A | D18 | SMA_L4.3-W2.6-LS5.0-RD |  | SMAJ90A | R+O(宏嘉诚) | C42394403 | LCSC
20 | 1 | 3.3uH | L2 | IND-SMD_L7.0-W6.6 | 3.3uH | FXL0630-3R3-M | cjiang(长江微电) | C167219 | LCSC
21 | 1 | 4.7uH | L3 | IND-SMD_L3.0-W3.0_FNR30XXS | 4.7uH | SWPA3012S4R7MT | Sunlord(顺络) | C83415 | LCSC
22 | 1 | 82uH | L4 | IND-SMD_L13.5-W12.6_125CDMCC-DS | 82uH | TMPC1206HP-820MG-D | TAI-TECH(台庆) | C357267 | LCSC
23 | 2 | 2.2uH | L5,L6 | IND-SMD_L3.2-W2.5-BRL3225T100M | 2.2uH | MTQH322520S2R2MBT | MetalLions(美铼) | C17701269 | LCSC
24 | 1 | 10uH | L7 | IND-SMD_L11.5-W10.0_SMMS1040 | 10uH | YSPI1050-100M | YJYCOIN(益嘉源) | C497897 | LCSC
25 | 3 | KT-0603R | LED2,LED3,LED4 | LED-SMD_L1.6-W0.8-R-RD |  | KT-0603R | KENTO | C2286 | LCSC
26 | 2 | CSD17578Q5A | Q1,Q2 | DFN-8_L5.8-W4.9-P1.27-LS6.0-BL-1 |  | CSD17578Q5A | TI(德州仪器) | C2871447 | LCSC
27 | 2 | CSD18563Q5A | Q3,Q4 | DFN-8_L5.7-W5.1-P1.27-LS6.0-BL |  | CSD18563Q5A | TI(德州仪器) | C77239 | LCSC
28 | 5 | XR30P10F | Q5,Q6,Q7,Q8,Q9 | TDSON-8_L5.9-W5.2-P1.27-BL-1 |  | XR30P10F | XNRUSEMI(新锐) | C53454473 | LCSC
29 | 1 | MMBT5401(RANGE:200-300) | Q10 | SOT-23-3_L2.9-W1.3-P1.90-LS2.4-BR |  | MMBT5401(RANGE:200-300) | CJ(江苏长电/长晶) | C8326 | LCSC
30 | 15 | 51Ω | R1,R2,R5,R6,R9,R11,R12,R18,R25,R26,R27,R38,R47,R48,R73 | R0603 | 51Ω | 0603WAF510JT5E | UNI-ROYAL(厚声) | C23197 | LCSC
31 | 6 | 5mΩ | R3,R4,R43,R44,R45,R46 | R0805 | 5mΩ | HoYLR0805-1/2W-5mR-1% | Milliohm(毫欧) | C22450690 | LCSC
32 | 2 | 27kΩ | R7,R14 | R0603 | 27kΩ | 0603WAF2702T5E | UNI-ROYAL(厚声) | C22967 | LCSC
33 | 2 | 2kΩ | R8,R61 | R0603 | 2kΩ | 0603WAF2001T5E | UNI-ROYAL(厚声) | C22975 | LCSC
34 | 2 | 100kΩ | R10,R15 | R0603 | 100kΩ | 0603WAF1003T5E | UNI-ROYAL(厚声) | C25803 | LCSC
35 | 1 | 150kΩ | R13 | R0603 | 150kΩ | 0603WAF1503T5E | UNI-ROYAL(厚声) | C22807 | LCSC
36 | 4 | 1MΩ | R16,R17,R59,R69 | R0603 | 1MΩ | 0603WAF1004T5E | UNI-ROYAL(厚声) | C22935 | LCSC
37 | 2 | 330kΩ | R19,R62 | R0603 | 330kΩ | 0603WAF3303T5E | UNI-ROYAL(厚声) | C23137 | LCSC
38 | 8 | 51kΩ | R20,R37,R40,R58,R64,R65,R78,R79 | R0603 | 51kΩ | 0603WAF5102T5E | UNI-ROYAL(厚声) | C23196 | LCSC
39 | 4 | 12kΩ | R21,R24,R52,R57 | R0603 | 12kΩ | 0603WAF1202T5E | UNI-ROYAL(厚声) | C22790 | LCSC
40 | 2 | 330Ω | R22,R76 | R0603 | 330Ω | 0603WAF3300T5E | UNI-ROYAL(厚声) | C23138 | LCSC
41 | 6 | 2Ω | R28,R29,R30,R31,R32,R33 | R0603 | 2Ω | 0603WAF200KT5E | UNI-ROYAL(厚声) | C22977 | LCSC
42 | 1 | 4.7Ω | R34 | R0805 | 4.7Ω | 0805W8F470KT5E | UNI-ROYAL(厚声) | C17675 | LCSC
43 | 7 | 0Ω | R36,R39,R41,R42,R54,R56,R68 | R0603 | 0Ω | 0603WAF0000T5E | UNI-ROYAL(厚声) | C21189 | LCSC
44 | 1 | 20kΩ | R51 | R0603 | 20kΩ | 0603WAF2002T5E | UNI-ROYAL(厚声) | C4184 | LCSC
45 | 3 | 3.3kΩ | R53,R71,R72 | R0603 | 3.3kΩ | 0603WAF3301T5E | UNI-ROYAL(厚声) | C22978 | LCSC
46 | 6 | 100kΩ | R60,R74,R80,R81,R82,R83 | R0805 | 100kΩ | 0805W8F1003T5E | UNI-ROYAL(厚声) | C149504 | LCSC
47 | 1 | 3.6kΩ | R66 | R0603 | 3.6kΩ | 0603WAF3601T5E | UNI-ROYAL(厚声) | C22980 | LCSC
48 | 1 | EG4427 | U1 | SOP-8_L4.9-W3.9-P1.27-LS6.0-BL |  | EG4427 | EG(屹晶微) | C2929102 | LCSC
49 | 1 | TPS55289RYQR | U2 | VQFN-21_L5.0-W3.0-P0.50-TL |  | TPS55289RYQR | TI(德州仪器) | C5942077 | LCSC
50 | 1 | LM5013DDAR | U3 | ESOP-8_L4.9-W3.9-P1.27-LS6.0-BL-EP-1 |  | LM5013DDAR | TI(德州仪器) | C5383001 | LCSC
51 | 2 | INA238AIDGSR | U4,U7 | VSSOP-10_L3.0-W3.0-P0.50-LS4.9-BL |  | INA238AIDGSR | TI(德州仪器) | C2868250 | LCSC
52 | 1 | MCP4725A0T-E/CH | U5 | SOT-23-6_L2.9-W1.6-P0.95-LS2.8-BL |  | MCP4725A0T-E/CH | MICROCHIP(美国微芯) | C144198 | LCSC
53 | 1 | AP63203WU-7 | U6 | TSOT-26_L2.9-W1.6-P0.95-LS2.8-BL |  | AP63203WU-7 | DIODES(美台) | C780769 | LCSC
54 | 1 | ZX-SH1.0-8PWT | U8 | CONN-SMD_8P-P1.00_MEGASTAR_ZX-SH1.0-8PWT |  | ZX-SH1.0-8PWT | Megastar(兆星) | C7430450 | LCSC
55 | 1 | LM51772RHAR | U10 | QFN-40_L6.0-W6.0-P0.50-TL-EP4.5-1 |  | LM51772RHAR | TI(德州仪器) | C41383743 | LCSC
56 | 1 | 100mΩ | U11 | R1206 | 100mΩ | FRM121WFR100TM | FOJAN(富捷) | C7467250 | LCSC
57 | 1 | TPS73801DCQR | U13 | SOT-223-6_L6.5-W3.5-P1.27-BL |  | TPS73801DCQR | TI(德州仪器) | C180428 | LCSC
58 | 1 | HUSB238A-BB001-QN16R | U17 | QFN-16_L3.0-W3.0-P0.50-BL-EP1.7 |  | HUSB238A-BB001-QN16R | Hynetek(慧能泰) | C24833806 | LCSC
59 | 1 | GT-USB-7010AW | USB1 | USB-SMD_GT-USB-7010AN |  | GT-USB-7010AW | G-Switch(品赞) | C963411 | LCSC
60 | 7 | BZT52C15S | ZD1,ZD2,ZD3,ZD4,ZD5,ZD6,ZD7 | SOD-323_L1.8-W1.3-LS2.5-RD |  | BZT52C15S | CJ(江苏长电/长晶) | C17283 | LCSC

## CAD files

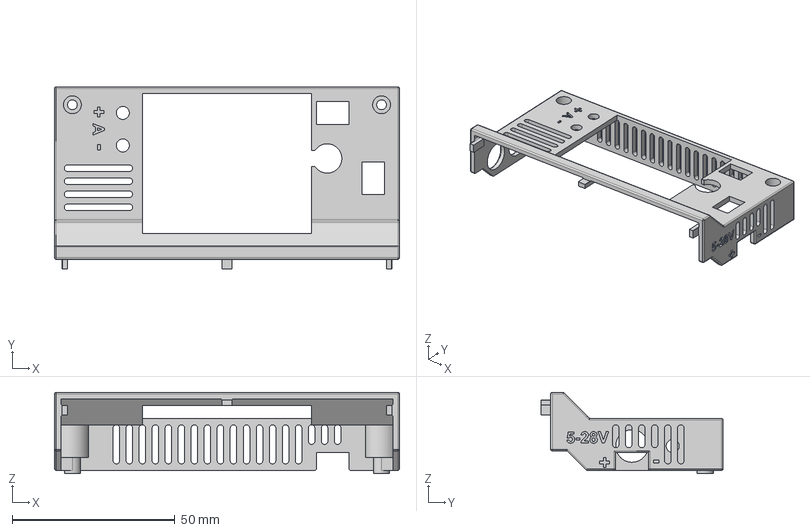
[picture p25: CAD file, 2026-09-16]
mechanical/Top_case_v1_final.step
106.0 x 56.0 x 25.0 mm

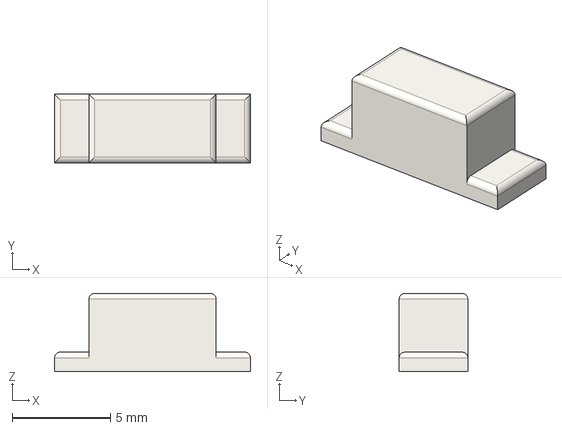
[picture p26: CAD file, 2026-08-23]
mechanical/Button_v1_x3_final_1.step
10.0 x 3.50 x 4.00 mm

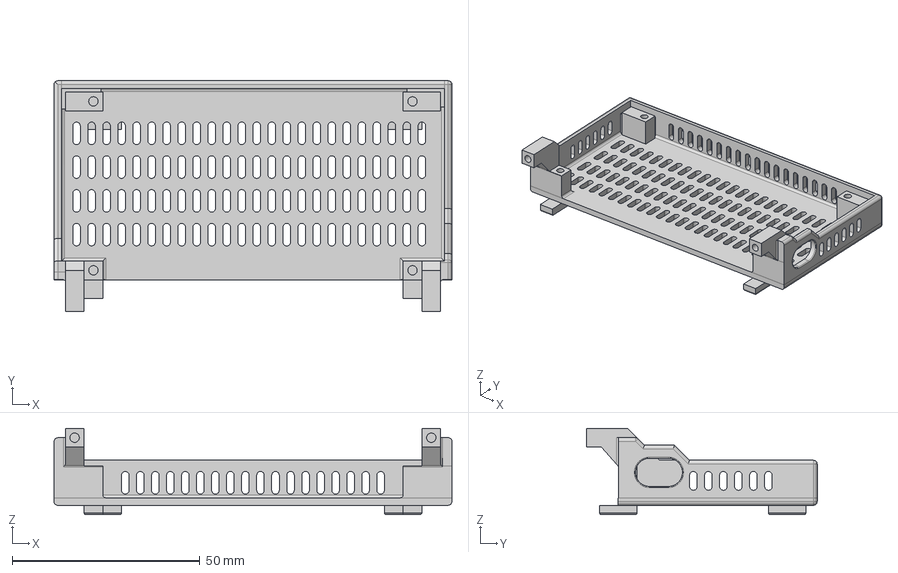
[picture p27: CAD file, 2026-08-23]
mechanical/Bottom_v1_final_1.step
106.0 x 61.4 x 23.0 mm

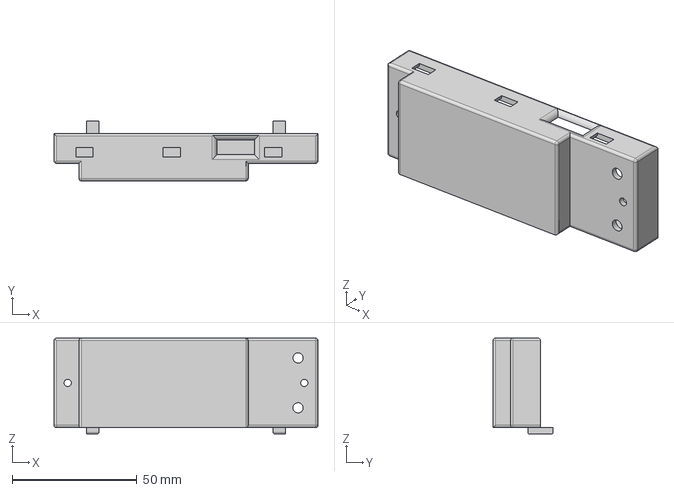
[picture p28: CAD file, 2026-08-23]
mechanical/Front_v1_final_1.step
106.0 x 24.0 x 38.5 mm

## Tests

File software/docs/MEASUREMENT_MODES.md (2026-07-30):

# DOGS² firmware modes

This document describes the current v1 engineering-sample build. It replaces
the earlier Logic_v1/Cheap Yellow Display notes.

## Power Source

The main screen controls both output channels and displays their measured
voltage and current. The firmware communicates with the power converters,
current monitors, DAC, and control-panel I/O over the main I²C bus. It also
handles channel enable, current limiting, status reporting, temperature,
input-voltage measurement, and output-voltage trim.

## Generator

The generator output uses the dedicated engineering-sample output pin.
Frequency, duty cycle, and output state are adjustable from the front panel.

## UART, LIN, and RS485

UART and RS485 provide configurable terminal operation and forward received
data over Bluetooth SPP. LIN currently uses the shared serial receive path and
its own baud/filter controls; protocol-aware LIN decoding remains in
development.

## CAN

The CAN mode uses the board transceiver and ESP32 TWAI controller. It supports
selectable bitrate, receive filtering, frame display and Bluetooth reporting,
plus frame transmission through Bluetooth commands.

## I²C

- **I²C Sniffer** passively captures traffic and applies an address filter.
- **I²C Master** provides scan and read/write commands at 100 kHz.

See [`I2C_MASTER_TERMINAL.md`](I2C_MASTER_TERMINAL.md) for the command syntax.

## Analog and frequency inputs

The analog path measures the external probe/input voltage and classifies logic
levels. The dedicated frequency input is counted by the ESP32 pulse counter.
These paths are described in [`ANALOG_CHANNEL.md`](ANALOG_CHANNEL.md) and
[`FREQUENCY_TIME.md`](FREQUENCY_TIME.md).

## In development

- 1-Wire protocol decoding;
- full protocol-aware LIN decoding;
- continued calibration, protection tuning, and hardware characterization.

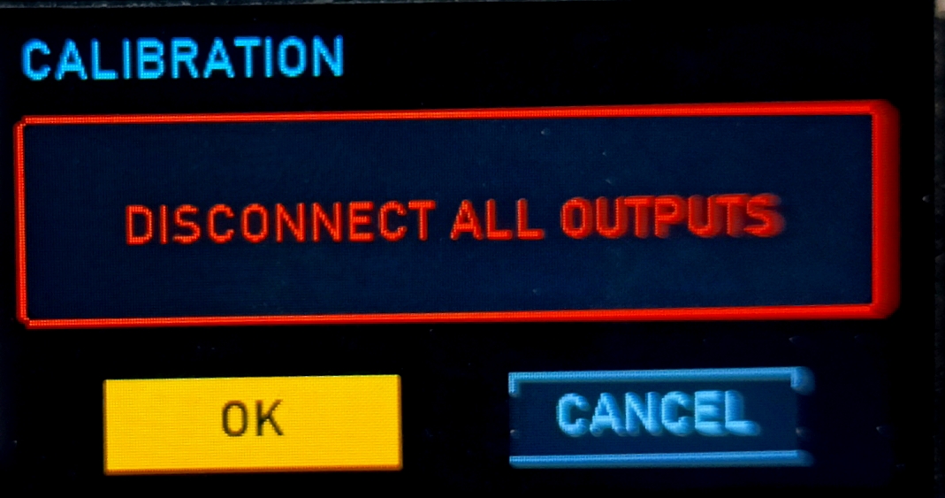
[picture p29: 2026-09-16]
assets/photos/calibration_warning.jpg

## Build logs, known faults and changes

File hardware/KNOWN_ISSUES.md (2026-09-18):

# DOGS2 v1 hardware known issues

These notes describe known issues in the current `v1` engineering-sample
hardware and the intended direction for the next board revision.

1. The U10 LM51772 reset needs to be pulled up to the input voltage by connecting pins 38 and 36 — there is a test point on the board.
2. Dirty DAC power — a separate 3.3 V LDO from Vin is needed — SE8633.
Remove capacitors or move them, drill out the via, solder the capacitors (don't forget — the jumper will also be drilled out), solder the regulator onto the DAC capacitors on top.
This can also be skipped, but then the ripple at output A will be 20 mV p-p.
3. Replace R66 3.6 kOhm with an RCR network: 1.8 + 0.1 µF to ground + 1.8 kOhm, and another 10k in parallel with one of the resistors. This also reduces ripple at output A.
4. Raise the TPS frequency to 600 kHz — resistor R10 33 kOhm instead of 100 kOhm.
5. Replace the TPS feedback loop compensation with R14 4.7 kOhm + C34 0.1 uF.
6. Remove R13 — the resistor on CDC.
7. On the control board, switch the BOOT pull-up resistor R12 from +3.3SW to +3.3 constant supply (next to R12 there is a programming connector pad with +3.3) — otherwise it won't turn on.
8. Electrolytic capacitors are needed: 220uF * 16V on the control panel board and 220uF * 35V on the power board; the footprints are there.
9. Turn off the input voltage monitoring LED LED3 and dim the +3.3 monitoring LED LED2 by moving the 12k resistor from R24 to R22 — there will be a dim standby backlight underneath.

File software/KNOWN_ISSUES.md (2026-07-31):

# DOGS2 v1 software known issues

These notes track firmware behavior that still needs adjustment in the current
`v1` engineering sample.

1. Output-voltage convergence should be more aggressive when the error is large. The current control loop reaches the setpoint too slowly, and it likely needs a first-boot no-load calibration path.
2. Current measurement and UI display accuracy still need tuning. Averaging modes should be rechecked to find a better balance between update speed and reading stability.
3. The least-significant-digit display hysteresis still needs validation.

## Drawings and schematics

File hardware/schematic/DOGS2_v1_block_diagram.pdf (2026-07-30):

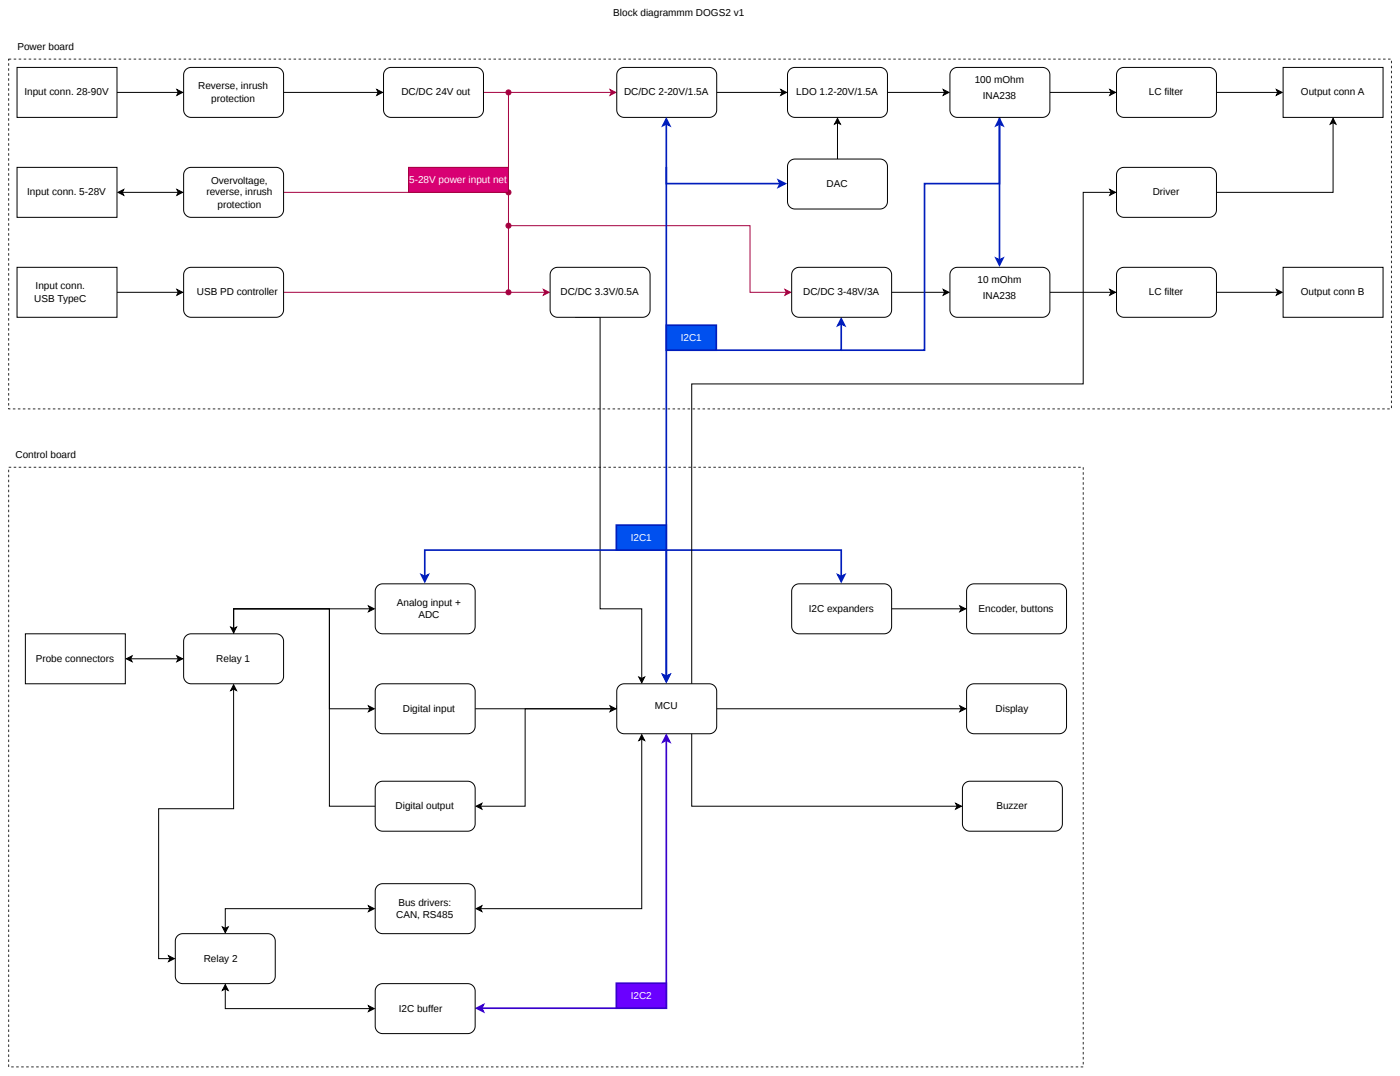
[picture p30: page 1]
Reverse, inrush; protection; DC/DC 24V out; LDO 1.2-20V/1.5A; 100 mOhm; INA238; LC filter; Output conn A; Driver; Output conn B; Input conn. 28-90V; Input conn.; USB TypeC; MCU; Display; Analog input + ADC; Digital input; Digital output; Bus drivers: CAN, RS485; I2C buffer; Probe connectors; Overvoltage, reverse, inrush protection; DAC; I2C expanders; Encoder, buttons; Buzzer; Relay 1; Relay 2; Input conn. 5-28V; Power board; Control board; Block diagrammm DOGS2 v1

5-28V power input net

10 mOhm INA238

USB PD controller

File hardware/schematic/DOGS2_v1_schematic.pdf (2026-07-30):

20V max.

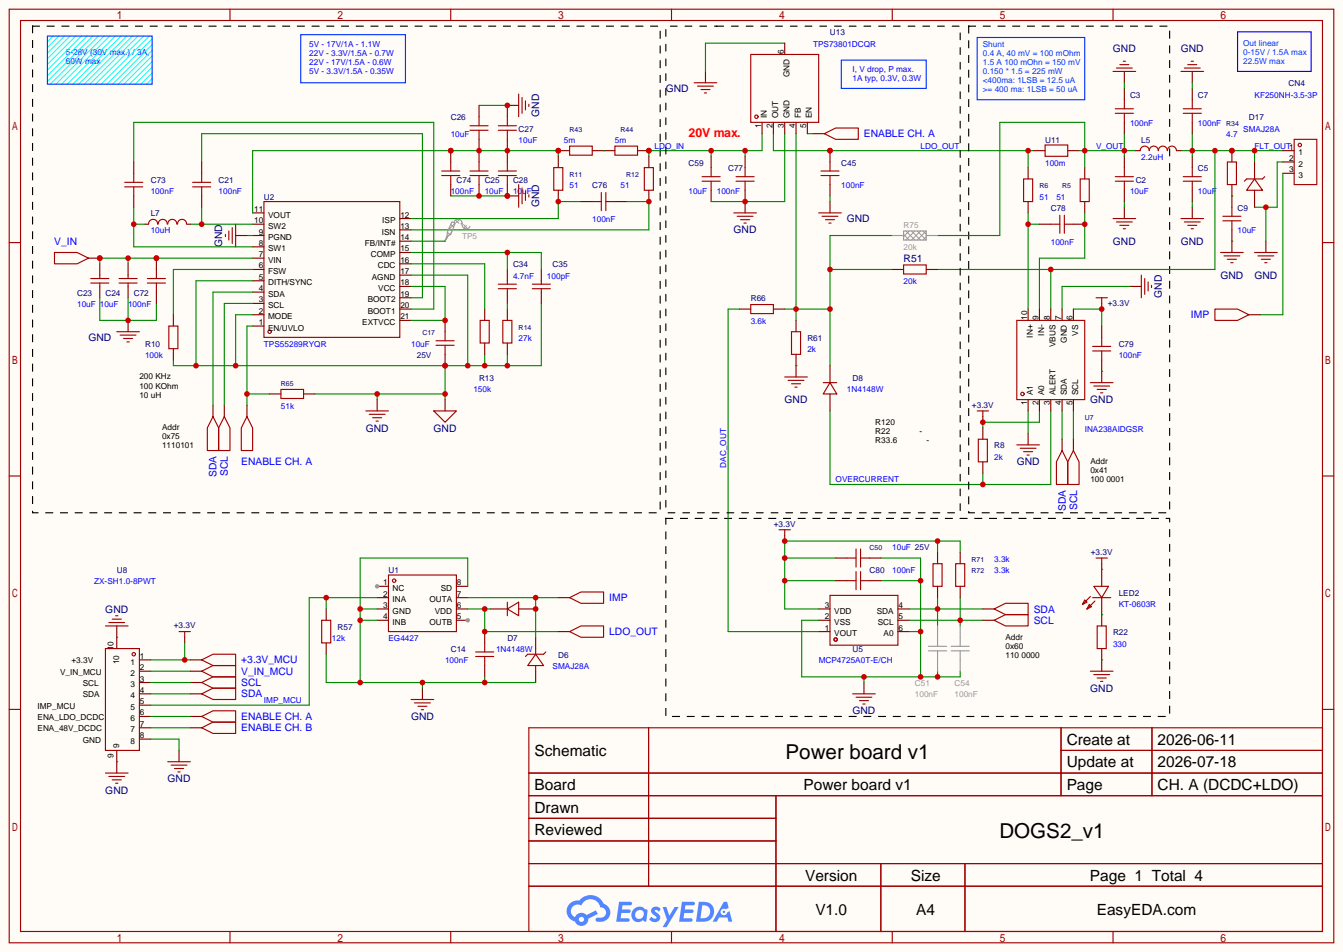
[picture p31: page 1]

Schematic | Power board v1 | Create at | 2026-06-11

Update at | 2026-07-18

Board | Power board v1 | Page | CH. A (DCDC+LDO)
Drawn | | DOGS2_v1
Reviewed

Version | Size | Page 1 Total 4
V1.0 | A4 | EasyEDA.com

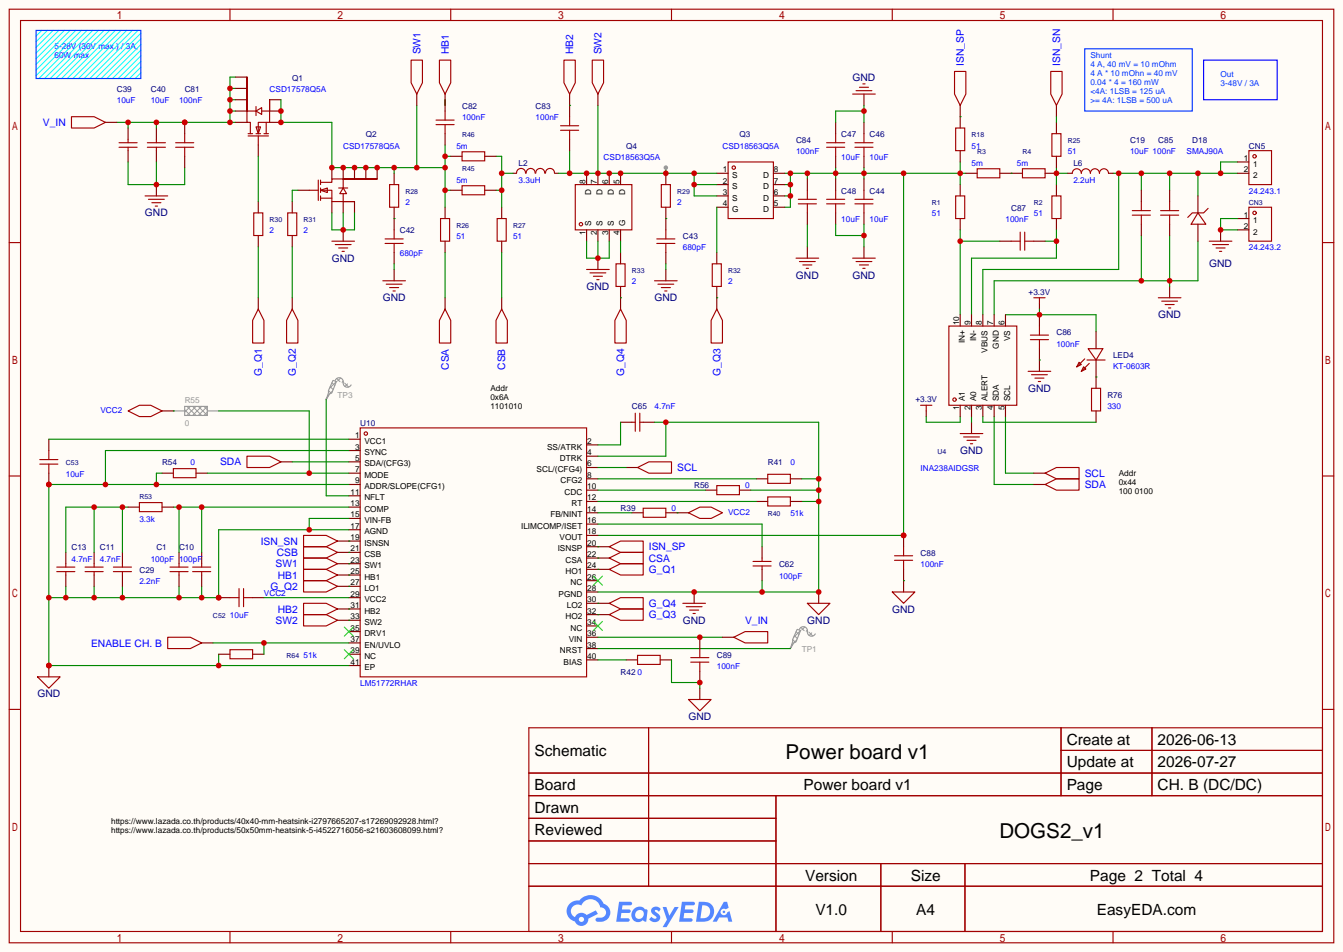
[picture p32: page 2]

Schematic | Power board v1 | Create at | 2026-06-13

Update at | 2026-07-27

Board | Power board v1 | Page | CH. B (DC/DC)
Drawn | | DOGS2_v1
Reviewed

https://www.lazada.co.th/products/40x40-mm-heatsink-i2797665207-s17269092928.html?
https://www.lazada.co.th/products/50x50mm-heatsink-5-i4522716056-s21603608099.html?

GND B1A12 VBUS B4A9 CC2 B5 SBU1 A8 D2+ B6 D1- A7 D1+ A6 D2- B7 CC1 A5 SBU2 B8 VBUS A4B9 GND A1B12

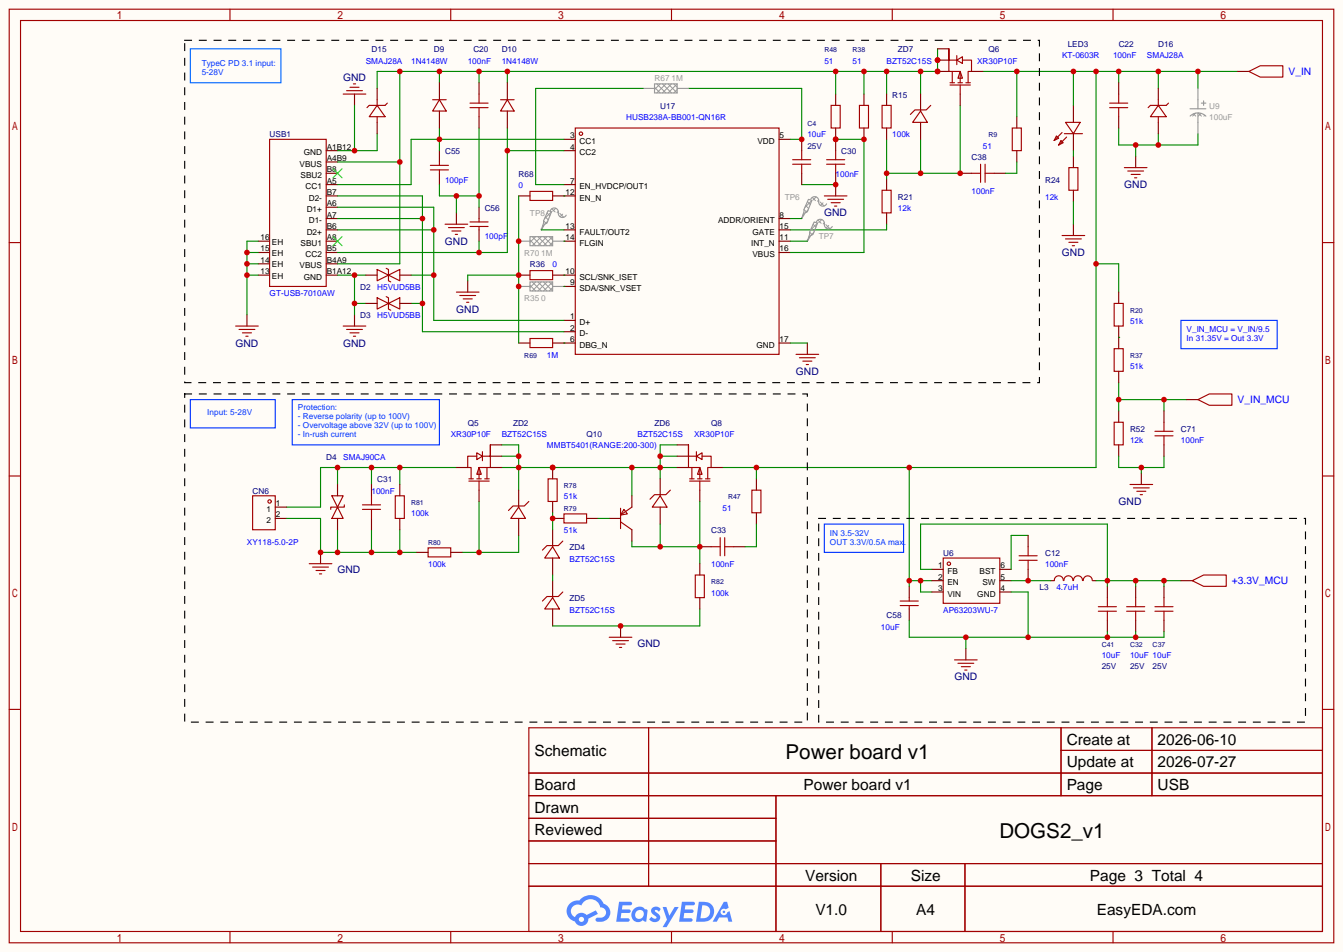
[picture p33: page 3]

VBUS 16 INT_N 11 GATE 15 ADDR/ORIENT 8

Protection:
- Reverse polarity (up to 100V)
- Overvoltage above 32V (up to 100V)
- In-rush current

Schematic | Power board v1 | Create at | 2026-06-10

Update at | 2026-07-27

Board | Power board v1 | Page | USB
Drawn | | DOGS2_v1
Reviewed

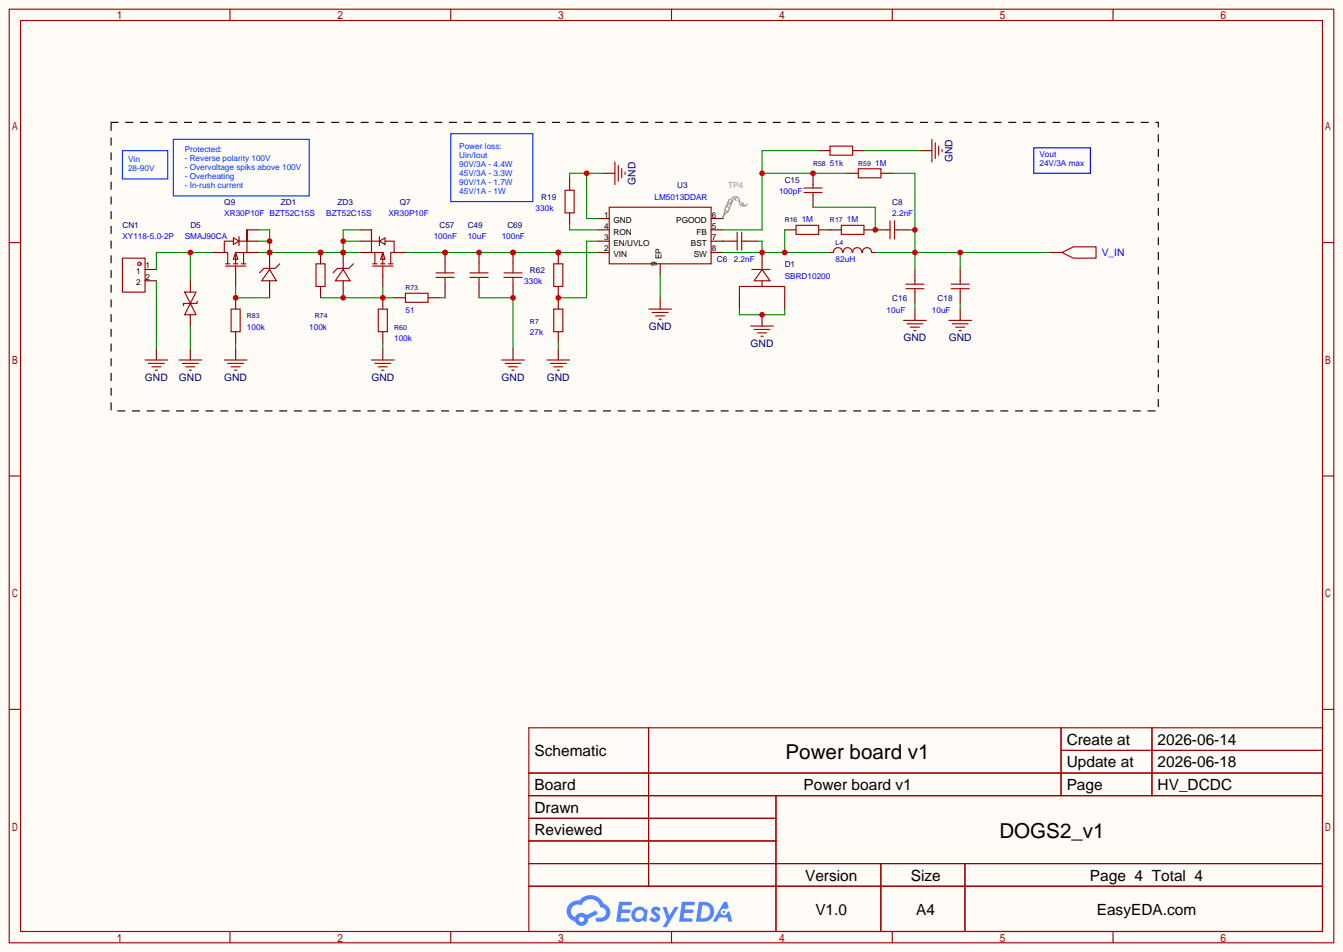
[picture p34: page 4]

Schematic | Power board v1 | Create at | 2026-06-14

Update at | 2026-06-18

Board | Power board v1 | Page | HV_DCDC
Drawn | | DOGS2_v1
Reviewed

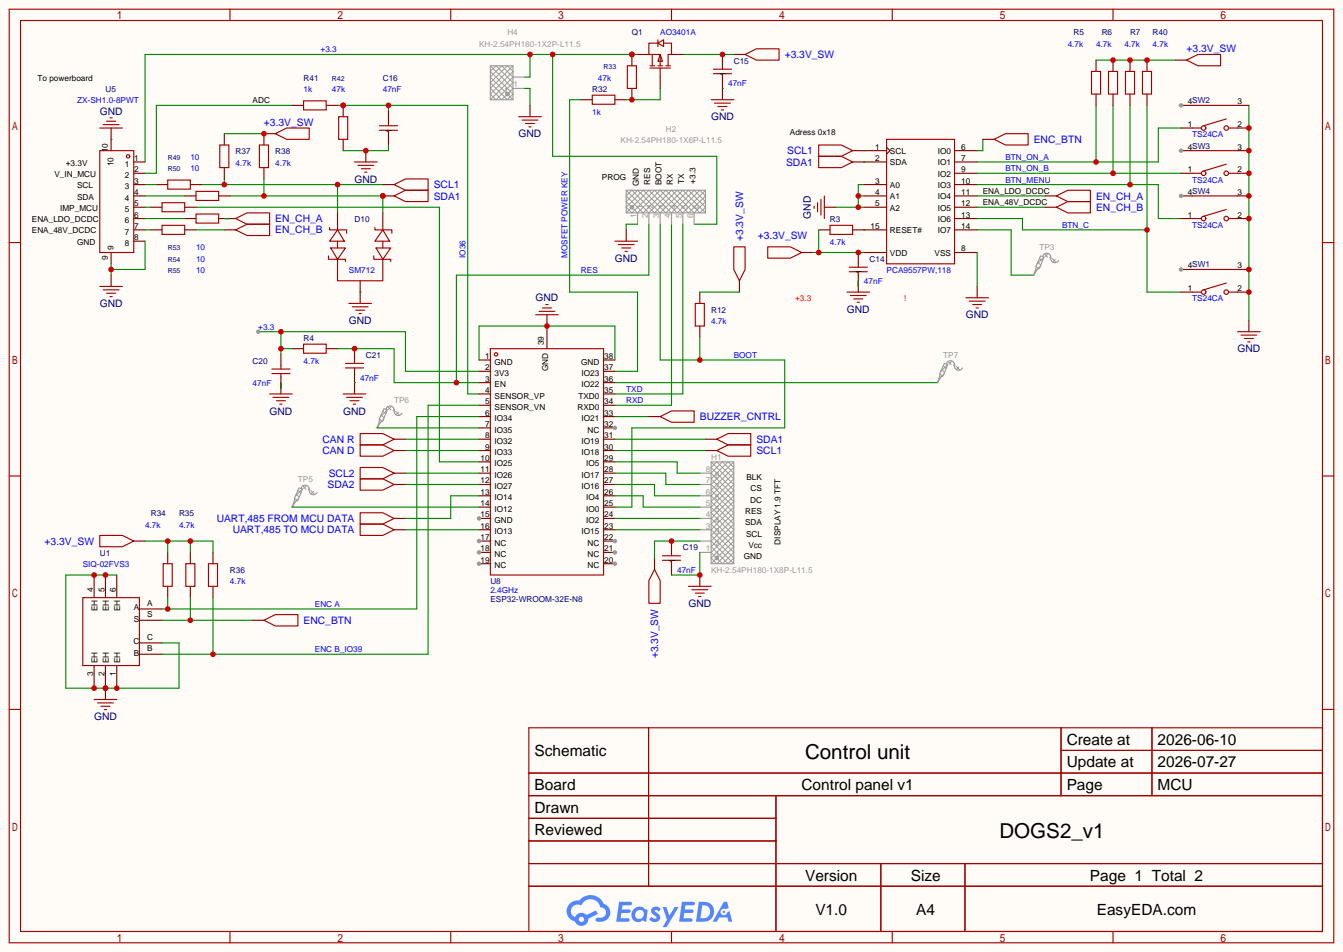
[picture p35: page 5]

UART,485 FROM MCU DATA
UART,485 TO MCU DATA

Schematic | Control unit | Create at | 2026-06-10

Update at | 2026-07-27

Board | Control panel v1 | Page | MCU
Drawn | | DOGS2_v1
Reviewed

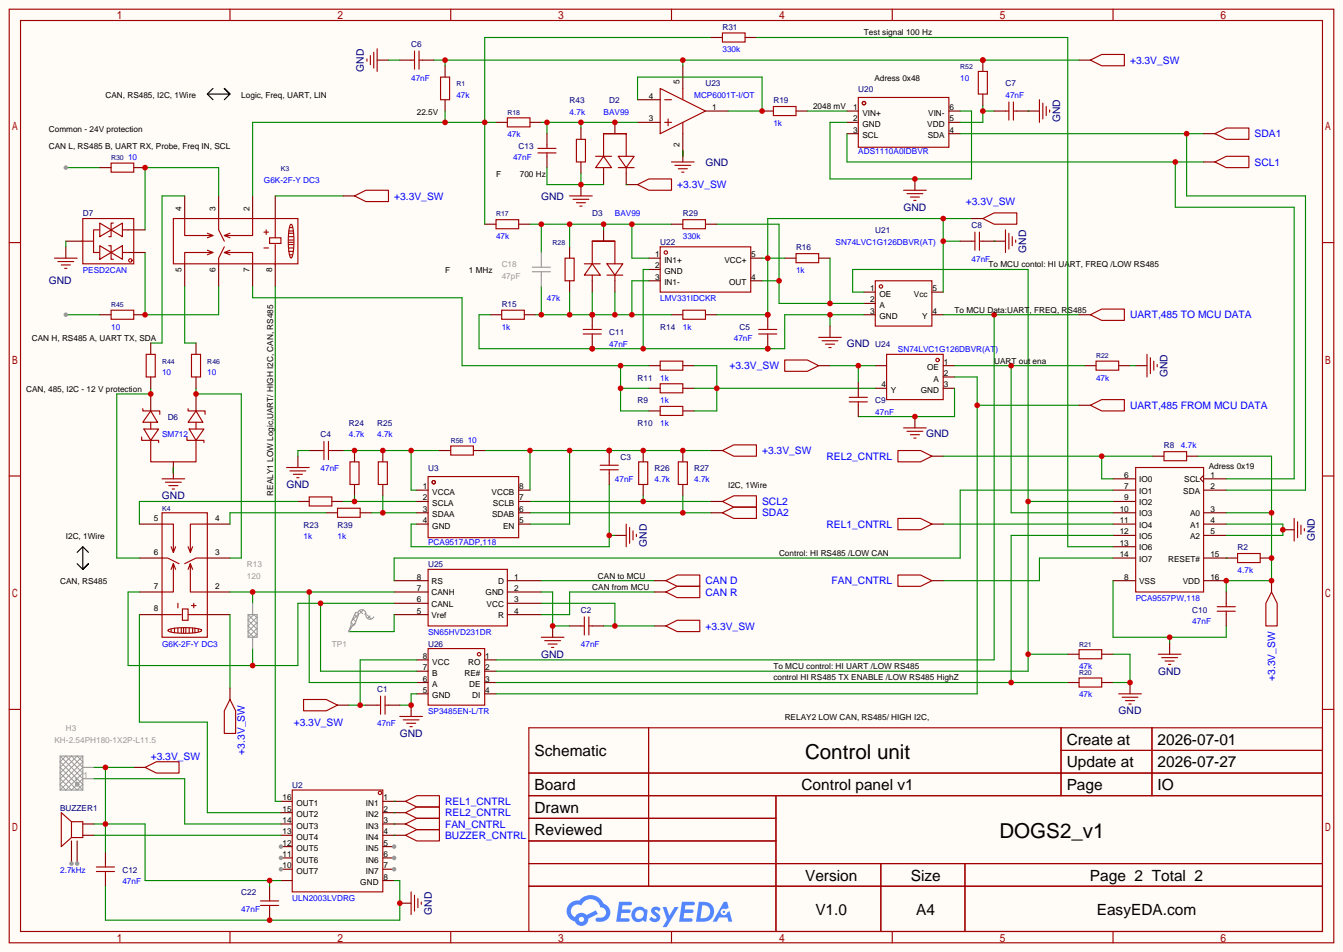
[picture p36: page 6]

Common - 24V protection
CAN L, RS485 B, UART RX, Probe, Freq IN, SCL

To MCU contol: HI UART, FREQ /LOW RS485

REALY1 LOW Logic,UART/ HIGH I2C, CAN, RS485

UART,485 TO MCU DATA
R8 4.7k GND

CAN H, RS485 A, UART TX, SDA

UART,485 FROM MCU DATA

Control: HI RS485 /LOW CAN

To MCU control: HI UART /LOW RS485
control HI RS485 TX ENABLE /LOW RS485 HighZ

Schematic | Control unit | Create at | 2026-07-01

Update at | 2026-07-27

Board | Control panel v1 | Page | IO
Drawn | | DOGS2_v1
Reviewed

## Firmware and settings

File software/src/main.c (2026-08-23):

#include <stdio.h>
#include <string.h>
#include "bluetooth_spp.h"
#include "buzzer.h"
#include "calibration.h"
#include "can_probe.h"
#include "channelA.h"
#include "channelB.h"
#include "control.h"
#include "display.h"
#include "driver/gpio.h"
#include "esp_attr.h"
#include "esp_check.h"
#include "esp_log.h"
#include "esp_system.h"
#include "esp_timer.h"
#include "freertos/FreeRTOS.h"
#include "freertos/queue.h"
#include "freertos/task.h"
#include "i2c_bus.h"
#include "i2c_i2s_sniffer.h"
#include "i2c_master_terminal.h"
#include "i2c_sniffer.h"
#include "i2c_worker.h"
#include "ina238_monitor.h"
#include "io26_diag.h"
#include "nvs_flash.h"
#include "analog_probe.h"
#include "probe_config.h"
#include "timing_input.h"
#include "uart_probe.h"

/*
 * Main scheduling model
 * ---------------------
 * app_main() intentionally does not read measurement hardware directly. Fast
 * edge timing is captured asynchronously by the MCPWM ISR inside
 * timing_input.c. UART A RX runs in its own FreeRTOS task inside uart_probe.c.
 * Bluetooth SPP also calls
 * back from its stack-owned task and only enqueues command bytes.
 *
 * The main loop is a cooperative scheduler:
 *
 *   every loop, about each 2 ms:
 *     - timing_input_update(&state, now)
 *       Copies capture/PCNT results into state.timing.
 *     - analog_probe_update(&state, timing_quiet)
 *       Reads the ADC window and updates state.analog.
 *     - uart_probe_update(&state)
 *       Copies UART RX text/errors into state.uart.
 *
 *   every UI_PERIOD_MS:
 *     - display_render()
 *       Draws only from the local snapshot.  The display does not read hardware.
 *
 *   every loop:
 *     - queued command processing.
 *
 * Result storage map
 * ------------------
 * timing_input.c:
 *   - ISR-owned volatile counters: edge count, last high/low/period, min/max.
 *   - task-owned derived state: last activity time, event hold timer.
 *   - output type: app_timing_state_t, copied by timing_input_update().
 *
 * analog_probe.c:
 *   - ADC calibration handle.
 *   - OPEN/prozvonka latch counters and last test amplitude.
 *   - output storage: state.analog.
 *
 * uart_probe.c:
 *   - last completed UART A display line.
 *   - UART A receive error counter.
 *   - output storage: state.uart.
 *
 * ina238_monitor.c:
 *   - I2C device addresses, shunt values and selected shunt ADC range.
 *   - output storage: state.ina238.
 *
 * channelA.c:
 *   - takes U2/I2 setpoints from state.control.
 *   - programs/publishes TPS55289 channel-A output state.
 *
 * channelB.c:
 *   - takes U1/I1 setpoints from state.control.
 *   - programs/publishes LM51772 channel-B output state.
 *
 * display.c:
 *   - previous rendered strings and rounded voltage values, used only to avoid
 *     flicker and redraw unchanged lines.
 */

static const char *TAG = "logic_probe";
static QueueHandle_t s_commands;
static char s_command_line[32];
static size_t s_command_line_used;
static int64_t s_command_line_last_us;
static app_state_t s_state;
static bool s_i2c_i2s_sniffer_active;
static app_mode_t s_i2c_gpio_configured_mode = APP_MODE_POWER_SUPPLY;
static app_mode_t s_bluetooth_configured_mode = APP_MODE_POWER_SUPPLY;

static void bluetooth_command(char command);

#define BOOT_STAGE_MAGIC 0xD0952001UL

typedef enum {
    BOOT_STAGE_UNKNOWN = 0,
    BOOT_STAGE_APP_MAIN,
    BOOT_STAGE_NVS_OK,
    BOOT_STAGE_IO23_CONFIGURED_INACTIVE,
    BOOT_STAGE_IO23_ON,
    BOOT_STAGE_IO23_ON_DONE,
    BOOT_STAGE_BT_INIT,
    BOOT_STAGE_BT_INIT_DONE,
    BOOT_STAGE_DISPLAY_INIT,
    BOOT_STAGE_I2C_INIT,
    BOOT_STAGE_RUN,
} boot_stage_t;

static RTC_NOINIT_ATTR uint32_t s_boot_stage_magic;
static RTC_NOINIT_ATTR uint32_t s_boot_stage;

static const char *boot_stage_name(uint32_t stage)
{
    switch ((boot_stage_t)stage) {
        case BOOT_STAGE_APP_MAIN:                 return "APP_MAIN";
        case BOOT_STAGE_NVS_OK:                   return "NVS_OK";
        case BOOT_STAGE_IO23_CONFIGURED_INACTIVE: return "IO23_CONFIGURED_INACTIVE";
        case BOOT_STAGE_IO23_ON:                  return "IO23_ON";
        case BOOT_STAGE_IO23_ON_DONE:             return "IO23_ON_DONE";
        case BOOT_STAGE_BT_INIT:                  return "BT_INIT";
        case BOOT_STAGE_BT_INIT_DONE:             return "BT_INIT_DONE";
        case BOOT_STAGE_DISPLAY_INIT:             return "DISPLAY_INIT";
        case BOOT_STAGE_I2C_INIT:                 return "I2C_INIT";
        case BOOT_STAGE_RUN:                      return "RUN";
        default:                                  return "UNKNOWN";
    }
}

static void boot_stage_set(boot_stage_t stage)
{
    s_boot_stage_magic = BOOT_STAGE_MAGIC;
    s_boot_stage = (uint32_t)stage;
}

static int64_t measured_current_ua(char channel, const app_ina238_channel_t *measurement)
{
    if (measurement == NULL || !measurement->valid || measurement->shunt_uohm == 0U) return 0;
    int64_t current_ua = measurement->current_ua;
    uint8_t cal_channel = channel == 'A' ? CALIBRATION_CHANNEL_A : CALIBRATION_CHANNEL_B;
    if (calibration_current_available(cal_channel)) {
        return calibration_correct_current_ua(cal_channel, measurement->bus_mv, current_ua);
    }
    if (channel == 'A') {
        current_ua -= ((int64_t)measurement->bus_mv * CHANNEL_A_DIVIDER_LEAK_UA_PER_MV_NUM +
                       CHANNEL_A_DIVIDER_LEAK_UA_PER_MV_DEN / 2LL) /
                      CHANNEL_A_DIVIDER_LEAK_UA_PER_MV_DEN;
    }
    return current_ua;
}

static void power_telemetry_update(const app_state_t *state, int64_t now_us)
{
    static int64_t last_telemetry_us;

    if (state == NULL ||
        state->control.mode != APP_MODE_1WIRE ||
        !bluetooth_spp_connected()) {
        last_telemetry_us = now_us;
        return;
    }
    if (now_us - last_telemetry_us < TELEMETRY_PERIOD_MS * 1000LL) return;
    last_telemetry_us = now_us;

    const app_ina238_channel_t *a = &state->ina238.channel[0];
    const app_ina238_channel_t *b = &state->ina238.channel[1];
    int64_t ia_ua = measured_current_ua('A', a);
    int64_t ib_ua = measured_current_ua('B', b);
    char line[48];

    int length = snprintf(line,
                          sizeof(line),
                          "E%lld,%lld\r\n",
                          (long long)ia_ua,
                          (long long)ib_ua);
    if (length > 0) bluetooth_spp_write(line, (size_t)length);
}

static void bluetooth_mode_update(app_mode_t mode)
{
    static int64_t next_init_retry_us;
    static int64_t next_deinit_retry_us;
    int64_t now_us = esp_timer_get_time();

    if (mode == APP_MODE_POWER_SUPPLY) {
        if (!bluetooth_spp_initialized()) {
            s_bluetooth_configured_mode = APP_MODE_POWER_SUPPLY;
            return;
        }
        if (s_bluetooth_configured_mode == APP_MODE_POWER_SUPPLY && now_us < next_deinit_retry_us) {
            return;
        }
        esp_err_t result = bluetooth_spp_deinit();
        s_bluetooth_configured_mode = APP_MODE_POWER_SUPPLY;
        if (result != ESP_OK) {
            ESP_LOGE(TAG, "Bluetooth deinit: %s", esp_err_to_name(result));
            next_deinit_retry_us = now_us + 1000000LL;
        } else {
            ESP_LOGI(TAG, "Bluetooth off in Power Source");
            next_deinit_retry_us = now_us;
        }
        return;
    }

    if (!bluetooth_spp_initialized()) {
        if (now_us < next_init_retry_us) return;
        boot_stage_set(BOOT_STAGE_BT_INIT);
        esp_err_t result = bluetooth_spp_init(bluetooth_command);
        if (result != ESP_OK) {
            ESP_LOGE(TAG, "Bluetooth init: %s", esp_err_to_name(result));
            next_init_retry_us = now_us + 1000000LL;
            return;
        } else {
            ESP_LOGI(TAG, "Bluetooth device: %s", bluetooth_spp_device_name());
        }
        boot_stage_set(BOOT_STAGE_BT_INIT_DONE);
    }

    s_bluetooth_configured_mode = mode;
}

static const char *mode_hint_text(app_mode_t mode)
{
    switch (mode) {
        case APP_MODE_UART:
            return "[UART HINT] ASCII mode only. BT input -> UART TX. UART RX text preview -> [UART]. Select baud on screen.\r\n";
        case APP_MODE_LIN:
            return "[LIN HINT] Sniffer only. Select baud/mask on screen. RX -> [LIN]P:<PID> <data...> CRC_CL:OK/CRC_ENH:OK/PAR:ERR/CRC:ERR.\r\n";
        case APP_MODE_CAN:
            return "[CAN HINT] Send ASCII HEX: 4 ID digits + 0..8 data bytes. Example 0404112233 -> ID 0x404 data 11 22 33. RX -> [CAN].\r\n";
        case APP_MODE_RS485:
            return "[RS485 HINT] Send byte values as HEX. RX -> [485] HEX. Select baud on screen.\r\n";
        case APP_MODE_I2C:
            return "[I2C SNIFF HINT] Sniffer only. Select mask on screen: -- all, 4- = 0x40..0x4F, 41 = only 0x41. RX -> [I2C].\r\n";
        case APP_MODE_I2C_MASTER:
            return "[I2C MASTER HINT] ASCII commands: S | R addr reg len | W addr reg data... | RR addr len | WW addr data... . addr/reg/data HEX, len decimal.\r\n";
        default:
            return NULL;
    }
}

static void mode_hint_update(app_mode_t mode)
{
    static app_mode_t hinted_mode = APP_MODE_POWER_SUPPLY;
    static bool hint_sent;
    static bool bt_was_connected;

    bool bt_connected = bluetooth_spp_connected();
    bool mode_changed = mode != hinted_mode;
    bool connected_now = bt_connected && !bt_was_connected;

    if (mode == APP_MODE_POWER_SUPPLY) {
        hinted_mode = mode;
        hint_sent = false;
        bt_was_connected = bt_connected;
        return;
    }

    if (mode_changed) {
        hinted_mode = mode;
        hint_sent = false;
    }

    if (bt_connected && !hint_sent && (mode_changed || connected_now)) {
        const char *hint = mode_hint_text(mode);
        if (hint != NULL) {
            bluetooth_spp_write(hint, strlen(hint));
        }
        hint_sent = true;
    }

    if (!bt_connected) hint_sent = false;
    bt_was_connected = bt_connected;
}

static void warning_tone_update(const app_state_t *state, int64_t now_us)
{
    static bool overheat_latched;
    static bool overpower_latched;
    static int64_t next_overheat_us;
    static int64_t next_overpower_us;

    const app_ina238_channel_t *a = &state->ina238.channel[0];
    const app_ina238_channel_t *b = &state->ina238.channel[1];

    bool temperature_valid = a->valid || b->valid;
    int32_t max_temperature_mc = 0;
    if (a->valid && b->valid) {
        max_temperature_mc = a->temperature_mc > b->temperature_mc ?
                             a->temperature_mc : b->temperature_mc;
    } else if (a->valid) {
        max_temperature_mc = a->temperature_mc;
    } else if (b->valid) {
        max_temperature_mc = b->temperature_mc;
    }

    int32_t overheat_on_mc = (int32_t)state->control.overheat_c * 1000;
    int32_t overheat_off_mc = overheat_on_mc - 1000;
    if (temperature_valid && max_temperature_mc >= overheat_on_mc) {
        overheat_latched = true;
    } else if (!temperature_valid || max_temperature_mc <= overheat_off_mc) {
        overheat_latched = false;
        next_overheat_us = now_us;
    }

    int64_t total_power_mw = 0;
    if (a->valid && state->control.channel_a_enabled) {
        int64_t current_ua = measured_current_ua('A', a);
        if (current_ua > 0) total_power_mw += ((int64_t)a->bus_mv * current_ua) / 1000000LL;
    }
    if (b->valid && state->control.channel_b_enabled) {
        int64_t current_ua = measured_current_ua('B', b);
        if (current_ua > 0) total_power_mw += ((int64_t)b->bus_mv * current_ua) / 1000000LL;
    }

    if (state->control.overpower_w == 0U) {
        overpower_latched = false;
        next_overpower_us = now_us;
    } else {
        int64_t overpower_on_mw = (int64_t)state->control.overpower_w * 1000LL;
        int64_t overpower_off_mw = overpower_on_mw - 5000LL;
        if (overpower_off_mw < 0) overpower_off_mw = 0;
        if (total_power_mw >= overpower_on_mw) {
            overpower_latched = true;
        } else if (total_power_mw <= overpower_off_mw) {
            overpower_latched = false;
            next_overpower_us = now_us;
        }
    }

    if (overpower_latched && now_us >= next_overpower_us) {
        buzzer_play_overpower_warning(state->control.volume_percent);
        next_overpower_us = now_us + 3000000LL;
        return;
    }

    if (overheat_latched && now_us >= next_overheat_us) {
        buzzer_play_overheat_warning(state->control.volume_percent);
        next_overheat_us = now_us + 5000000LL;
    }
}

static uint64_t gpio_output_mask(gpio_num_t gpio)
{
    if (gpio == GPIO_NUM_NC) return 0ULL;
    return 1ULL << gpio;
}

static esp_err_t board_power_init(void)
{
    uint64_t pin_mask = gpio_output_mask(BOARD_PERIPHERAL_POWER_GPIO);
    if (pin_mask == 0ULL) return ESP_OK;
    int inactive_level = BOARD_PERIPHERAL_POWER_ACTIVE_LEVEL ? 0 : 1;

    gpio_set_level(BOARD_PERIPHERAL_POWER_GPIO, inactive_level);
    gpio_config_t output = {
        .pin_bit_mask = pin_mask,
        .mode = GPIO_MODE_OUTPUT,
        .pull_up_en = GPIO_PULLUP_DISABLE,
        .pull_down_en = GPIO_PULLDOWN_DISABLE,
        .intr_type = GPIO_INTR_DISABLE,
    };
    ESP_RETURN_ON_ERROR(gpio_config(&output), TAG, "peripheral power gpio");
    gpio_set_level(BOARD_PERIPHERAL_POWER_GPIO, inactive_level);
    ESP_LOGI(TAG, "peripheral power gpio %d inactive level %d",
             (int)BOARD_PERIPHERAL_POWER_GPIO,
             inactive_level);
    boot_stage_set(BOOT_STAGE_IO23_CONFIGURED_INACTIVE);
    return ESP_OK;
}

static void board_power_enable(void)
{
    if (BOARD_PERIPHERAL_POWER_GPIO == GPIO_NUM_NC) return;
#if BOARD_PERIPHERAL_POWER_AUTO_ENABLE
    boot_stage_set(BOOT_STAGE_IO23_ON);
    ESP_LOGI(TAG, "peripheral power gpio %d active level %d",
             (int)BOARD_PERIPHERAL_POWER_GPIO,
             BOARD_PERIPHERAL_POWER_ACTIVE_LEVEL);
    gpio_set_level(BOARD_PERIPHERAL_POWER_GPIO, BOARD_PERIPHERAL_POWER_ACTIVE_LEVEL);
    boot_stage_set(BOOT_STAGE_IO23_ON_DONE);
#else
    ESP_LOGW(TAG, "peripheral power auto enable disabled");
#endif
}

/* enqueue_command
 * Inputs:
 *   command - one command byte received from Bluetooth or USB UART.
 * Returns: none.
 * Does: places the command into the main-loop queue so command handling never
 * runs inside a Bluetooth callback or blocking input task.
 */
static void enqueue_command(char command)
{
    if (s_commands != NULL) xQueueSend(s_commands, &command, pdMS_TO_TICKS(10));
}

static void bluetooth_command(char command)
{
    if (can_probe_input_char(command)) return;
    if (i2c_master_terminal_input_char(command)) return;

#if UART_PROBE_ENABLED
    if (s_state.control.mode == APP_MODE_UART ||
        s_state.control.mode == APP_MODE_LIN ||
        s_state.control.mode == APP_MODE_RS485) {
        uart_probe_write_bytes(&command, 1U);
        return;
    }
#endif
    enqueue_command(command);
}

/* uart_command_task
 * Inputs:
 *   argument - unused FreeRTOS task argument.
 * Returns: never returns.
 * Does: reads command characters from USB stdin and forwards them to the same
 * queue that Bluetooth commands use.
 */
static void uart_command_task(void *argument)
{
    (void)argument;
    while (true) {
        int ch = getchar();
        if (ch != EOF) enqueue_command((char)ch);
        vTaskDelay(pdMS_TO_TICKS(10));
    }
}
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
void app_main(void)
{
    uint32_t previous_stage = s_boot_stage_magic == BOOT_STAGE_MAGIC ?
                              s_boot_stage : BOOT_STAGE_UNKNOWN;
    esp_reset_reason_t reset_reason = esp_reset_reason();
    ESP_LOGI(TAG, "boot Logic_v2 app_main");
    ESP_LOGI(TAG,
             "reset reason=%d previous boot stage=%s",
             (int)reset_reason,
             boot_stage_name(previous_stage));
    boot_stage_set(BOOT_STAGE_APP_MAIN);
    esp_err_t nvs = nvs_flash_init();
    if (nvs == ESP_ERR_NVS_NO_FREE_PAGES || nvs == ESP_ERR_NVS_NEW_VERSION_FOUND) {
        ESP_ERROR_CHECK(nvs_flash_erase());
        ESP_ERROR_CHECK(nvs_flash_init());
    } else {
        ESP_ERROR_CHECK(nvs);
    }
    boot_stage_set(BOOT_STAGE_NVS_OK);
    ESP_ERROR_CHECK(board_power_init());
    calibration_load();

    s_commands = xQueueCreate(64, sizeof(char));
    xTaskCreate(uart_command_task, "uart_cmd", 3072, NULL, 4, NULL);

    board_power_enable();

    memset(&s_state, 0, sizeof(s_state));
    s_state.analog.logic_state = PROBE_UNDEFINED;
    ESP_LOGI(TAG, "state initialized");

#if TIMING_INPUT_ENABLED
    ESP_LOGI(TAG, "timing_input_init");
    ESP_ERROR_CHECK(timing_input_init());
#endif
#if ANALOG_PROBE_ENABLED
    ESP_LOGI(TAG, "analog_probe_init");
    ESP_ERROR_CHECK(analog_probe_init());
#endif
    ESP_LOGI(TAG, "display_init begin");
    boot_stage_set(BOOT_STAGE_DISPLAY_INIT);
    ESP_ERROR_CHECK(display_init());
    ESP_LOGI(TAG, "display_init end");
#if IO26_DIAG_ENABLED
    ESP_LOGI(TAG, "io26_diag_init begin");
    ESP_ERROR_CHECK(io26_diag_init());
    ESP_LOGI(TAG, "io26_diag_init end");
#endif
#if UART_PROBE_ENABLED && !I2C_SNIFFER_OWNS_UART_PINS
    ESP_LOGI(TAG, "uart_probe_init");
    ESP_ERROR_CHECK(uart_probe_init());
#endif
#if I2C_SNIFFER_ENABLED
    ESP_LOGI(TAG, "i2c_i2s_sniffer_init");
    esp_err_t i2c_i2s_sniffer_result = i2c_i2s_sniffer_init();
    if (i2c_i2s_sniffer_result == ESP_OK) {
        s_i2c_i2s_sniffer_active = true;
    } else {
        ESP_LOGW(TAG,
                 "i2c_i2s_sniffer_init failed: %s, falling back to gpio sniffer",
                 esp_err_to_name(i2c_i2s_sniffer_result));
        ESP_ERROR_CHECK(i2c_sniffer_init());
    }
#endif
    ESP_LOGI(TAG, "i2c_master_terminal_init");
    ESP_ERROR_CHECK(i2c_master_terminal_init());
    ESP_LOGI(TAG, "can_probe_init");
    ESP_ERROR_CHECK(can_probe_init());
    ESP_LOGI(TAG, "buzzer_init begin");
    ESP_ERROR_CHECK(buzzer_init());
    ESP_LOGI(TAG, "buzzer_init end");
    ESP_LOGI(TAG, "control_init begin");
    ESP_ERROR_CHECK(control_init());
    ESP_LOGI(TAG, "control_init end");
    ESP_LOGI(TAG, "ina238_monitor_init begin");
    boot_stage_set(BOOT_STAGE_I2C_INIT);
    ESP_ERROR_CHECK(ina238_monitor_init());
    ESP_LOGI(TAG, "ina238_monitor_init end");
    ESP_LOGI(TAG, "channelA_init begin");
    ESP_ERROR_CHECK(channelA_init());
    ESP_LOGI(TAG, "channelA_init end");
    ESP_LOGI(TAG, "channelB_init begin");
    ESP_ERROR_CHECK(channelB_init());
    ESP_LOGI(TAG, "channelB_init end");
    ESP_LOGI(TAG, "i2c_worker_start begin");
    ESP_ERROR_CHECK(i2c_worker_start(&s_state));
    ESP_LOGI(TAG, "i2c_worker_start end");

    int64_t last_ui_us = 0;
    display_black();
    ESP_LOGI(TAG, "enter main loop");
    boot_stage_set(BOOT_STAGE_RUN);

    while (true) {
        int64_t now = esp_timer_get_time();
#if TIMING_INPUT_ENABLED
        timing_input_update(&s_state, (uint32_t)now);
#endif
#if ANALOG_PROBE_ENABLED
        analog_probe_update(&s_state, false);
#endif
        control_update(&s_state);
        bluetooth_mode_update(s_state.control.mode);
        mode_hint_update(s_state.control.mode);
#if UART_PROBE_ENABLED && !I2C_SNIFFER_OWNS_UART_PINS
        uart_probe_configure(s_state.control.mode,
                             s_state.control.uart_baud,
                             s_state.control.lin_baud,
                             s_state.control.rs485_baud,
                             s_state.control.lin_mask_value,
                             s_state.control.lin_mask_care);
        uart_probe_update(&s_state);
#endif
#if I2C_SNIFFER_ENABLED
        /*
         * Mode changes have two phases for modules sharing the external I2C
         * pins: first every previous owner is told to leave, then modules are
         * configured for the new mode.  No module needs to know which module
         * will own the pins next.
         */
        if (s_state.control.mode != s_i2c_gpio_configured_mode) {
            i2c_master_terminal_configure(APP_MODE_POWER_SUPPLY);
            if (s_i2c_i2s_sniffer_active) {
                i2c_i2s_sniffer_configure(APP_MODE_POWER_SUPPLY,
                                          s_state.control.i2c_mask_value,
                                          s_state.control.i2c_mask_care);
            } else {
                i2c_sniffer_configure(APP_MODE_POWER_SUPPLY,
                                      s_state.control.i2c_mask_value,
                                      s_state.control.i2c_mask_care);
            }
            s_i2c_gpio_configured_mode = s_state.control.mode;
        }

        i2c_master_terminal_configure(s_state.control.mode);
        if (s_i2c_i2s_sniffer_active) {
            i2c_i2s_sniffer_configure(s_state.control.mode,
                                      s_state.control.i2c_mask_value,
                                      s_state.control.i2c_mask_care);
        } else {
            i2c_sniffer_configure(s_state.control.mode,
                                  s_state.control.i2c_mask_value,
                                  s_state.control.i2c_mask_care);
        }
        if (s_i2c_i2s_sniffer_active) i2c_i2s_sniffer_update(&s_state);
        else i2c_sniffer_update(&s_state);
#else
        i2c_master_terminal_configure(s_state.control.mode);
#endif
        i2c_master_terminal_update(&s_state);
        can_probe_configure(s_state.control.mode,
                            s_state.control.can_bitrate,
                            s_state.control.can_mask_value,
                            s_state.control.can_mask_care);
        can_probe_update(&s_state, now);
        control_persistence_update(now);
        buzzer_set_volume(s_state.control.volume_percent);
        warning_tone_update(&s_state, now);
        buzzer_update();
        power_telemetry_update(&s_state, now);

        if (now - last_ui_us >= UI_PERIOD_MS * 1000LL) {
            last_ui_us = now;
            display_render(&s_state);
        }
        char command;
        while (xQueueReceive(s_commands, &command, 0) == pdTRUE) process_command_char(command);
        process_buffered_command_if_idle(now);
        vTaskDelay(pdMS_TO_TICKS(2));
    }
}

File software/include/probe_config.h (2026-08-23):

#pragma once

#include "driver/gpio.h"
#include "esp_adc/adc_oneshot.h"

/* Hardware revision selector.
 *
 * Default is the current hand-wired PoC.  Build the production engineering
 * sample with:
 *   -D LOGIC_V2_BOARD_REV=LOGIC_V2_BOARD_ENGINEERING_SAMPLE
 */
#define LOGIC_V2_BOARD_POC                1
#define LOGIC_V2_BOARD_ENGINEERING_SAMPLE 2
#ifndef LOGIC_V2_BOARD_REV
#define LOGIC_V2_BOARD_REV LOGIC_V2_BOARD_POC
#endif

/* ESP32-WROOM board with external ST7789 1.9" 170x320 SPI TFT. */
#define PROBE_ADC_CHANNEL       ADC_CHANNEL_0 /* GPIO36 / SENSOR_VP */
#define PROBE_ADC_GPIO          GPIO_NUM_36

#if LOGIC_V2_BOARD_REV == LOGIC_V2_BOARD_POC
#define PROBE_COMPARATOR_GPIO   GPIO_NUM_22
#define PROBE_BIAS_GPIO         GPIO_NUM_27
#define PROBE_TEST_SIGNAL_GPIO  GPIO_NUM_26
#define BOARD_PERIPHERAL_POWER_GPIO GPIO_NUM_NC
#elif LOGIC_V2_BOARD_REV == LOGIC_V2_BOARD_ENGINEERING_SAMPLE
#define PROBE_COMPARATOR_GPIO   GPIO_NUM_NC
#define PROBE_BIAS_GPIO         GPIO_NUM_NC
#define PROBE_TEST_SIGNAL_GPIO  GPIO_NUM_NC
#define BOARD_PERIPHERAL_POWER_GPIO GPIO_NUM_23
#define BOARD_PERIPHERAL_POWER_ACTIVE_LEVEL 0
#define BOARD_PERIPHERAL_POWER_AUTO_ENABLE 1
#else
#error "Unknown LOGIC_V2_BOARD_REV"
#endif

#ifndef BOARD_PERIPHERAL_POWER_ACTIVE_LEVEL
#define BOARD_PERIPHERAL_POWER_ACTIVE_LEVEL 1
#endif
#ifndef BOARD_PERIPHERAL_POWER_AUTO_ENABLE
#define BOARD_PERIPHERAL_POWER_AUTO_ENABLE 1
#endif

#define ANALOG_PROBE_ENABLED    1
#if LOGIC_V2_BOARD_REV == LOGIC_V2_BOARD_ENGINEERING_SAMPLE
#define TIMING_INPUT_ENABLED    1
#else
#define TIMING_INPUT_ENABLED    0
#endif
#define UART_PROBE_ENABLED      1
#define IO26_DIAG_ENABLED       0

/* Panel controls. Internal pull-ups are enabled in encoder_input.c/control.c
 * where the selected GPIO supports them.  Engineering-sample buttons are read
 * through PCA9557, so their direct GPIOs are intentionally not assigned here.
 */
#if LOGIC_V2_BOARD_REV == LOGIC_V2_BOARD_POC
#define ENCODER_A_GPIO          GPIO_NUM_13
#define ENCODER_B_GPIO          GPIO_NUM_27
#define ENCODER_BUTTON_GPIO     GPIO_NUM_14
#define UI_BUTTON_GPIO          GPIO_NUM_NC
#define MODE_BUTTON_GPIO        GPIO_NUM_32
#define GENERATOR_OUTPUT_GPIO   GPIO_NUM_23
#elif LOGIC_V2_BOARD_REV == LOGIC_V2_BOARD_ENGINEERING_SAMPLE
#define ENCODER_A_GPIO          GPIO_NUM_34
#define ENCODER_B_GPIO          GPIO_NUM_39
#define ENCODER_BUTTON_GPIO     GPIO_NUM_NC
#define UI_BUTTON_GPIO          GPIO_NUM_NC
#define MODE_BUTTON_GPIO        GPIO_NUM_NC
#define GENERATOR_OUTPUT_GPIO   GPIO_NUM_25
#endif

#if LOGIC_V2_BOARD_REV == LOGIC_V2_BOARD_ENGINEERING_SAMPLE
#define FREQUENCY_INPUT_GPIO    GPIO_NUM_13
#else
#define FREQUENCY_INPUT_GPIO    PROBE_COMPARATOR_GPIO
#endif

#if LOGIC_V2_BOARD_REV == LOGIC_V2_BOARD_ENGINEERING_SAMPLE
#define BUZZER_OUTPUT_GPIO      GPIO_NUM_21
#define CAN_RX_GPIO             GPIO_NUM_32
#define CAN_TX_GPIO             GPIO_NUM_33
#else
#define BUZZER_OUTPUT_GPIO      GPIO_NUM_NC
#define CAN_RX_GPIO             GPIO_NUM_NC
#define CAN_TX_GPIO             GPIO_NUM_NC
#endif

/* UART experiment. */
#if LOGIC_V2_BOARD_REV == LOGIC_V2_BOARD_POC
#define UART_A_RX_GPIO          GPIO_NUM_19
#define UART_A_TX_GPIO          GPIO_NUM_18
#elif LOGIC_V2_BOARD_REV == LOGIC_V2_BOARD_ENGINEERING_SAMPLE
#define UART_A_RX_GPIO          GPIO_NUM_13 /* UART/RS485 data from MCU */
#define UART_A_TX_GPIO          GPIO_NUM_14 /* UART/RS485 data to MCU */
#endif
#define UART_TEST_BAUD          115200
#define UART_PREVIEW_CHARS      25
#define UART_DISPLAY_CHARS      (UART_PREVIEW_CHARS + 3U)
#define I2C_DISPLAY_CHARS       (UART_DISPLAY_CHARS + 7U)

#if LOGIC_V2_BOARD_REV == LOGIC_V2_BOARD_POC
/* Passive I2C sniffer. External jumpers:
 *   IO26/SCL -> IO21
 *   IO25/SDA -> IO22
 */
#define I2C_SNIFFER_ENABLED     1
#define I2C_SNIFFER_SCL_GPIO    GPIO_NUM_21
#define I2C_SNIFFER_SDA_GPIO    GPIO_NUM_22
/* I2S1 drives BCK on IO19; I2S0 samples that same pad as its external clock. */
#define I2C_SNIFFER_I2S_CLOCK_OUT_GPIO GPIO_NUM_19
#define I2C_SNIFFER_I2S_CLOCK_IN_GPIO  GPIO_NUM_19
#define I2C_SNIFFER_OWNS_UART_PINS     1
#elif LOGIC_V2_BOARD_REV == LOGIC_V2_BOARD_ENGINEERING_SAMPLE
#define I2C_SNIFFER_ENABLED     1
#define I2C_SNIFFER_SCL_GPIO    GPIO_NUM_26
#define I2C_SNIFFER_SDA_GPIO    GPIO_NUM_27
#define I2C_SNIFFER_I2S_CLOCK_OUT_GPIO GPIO_NUM_12
#define I2C_SNIFFER_I2S_CLOCK_IN_GPIO  GPIO_NUM_12
#define I2C_SNIFFER_OWNS_UART_PINS     0
#endif
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

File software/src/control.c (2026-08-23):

#include "control.h"

#include <stddef.h>
#include <stdint.h>
#include <string.h>
#include "board_io.h"
#include "buzzer.h"
#include "calibration.h"
#include "current_graph.h"
#include "driver/gpio.h"
#include "encoder_input.h"
#include "esp_check.h"
#include "esp_timer.h"
#include "generator_output.h"
#include "nvs.h"
#include "probe_config.h"

/*
 * Control input module.
 *
 * GPIOs:
 *   ENCODER_A_GPIO - encoder A
 *   ENCODER_B_GPIO - encoder B
 *   UI_BUTTON_GPIO - optional external UI button
 *   ENCODER_BUTTON_GPIO - encoder push button, same action as UI_BUTTON_GPIO
 *   MODE_BUTTON_GPIO - mode button, active low
 * A press on either UI_BUTTON_GPIO or ENCODER_BUTTON_GPIO selects channel A
 * voltage first, then enters digit editing for the selected value. There is no
 * separate S button in Logic_v2.
 *
 * This module owns the user controls:
 *   - debounces external and encoder buttons;
 *   - consumes already-decoded encoder steps from encoder_input.c;
 *   - changes U1/I1/U2/I2 set values.
 *
 * Values are stored as integers:
 *   U1/U2 - millivolts, step 10 mV;
 *   I1/I2 - milliamps, step 10 mA.
 */

#define BUTTON_DEBOUNCE_US 25000LL
#define SETTINGS_SAVE_DELAY_US 1000000LL
#define EDIT_TIMEOUT_US 30000000LL
#define SETTINGS_NVS_NAMESPACE "setpoints"
#define CONTROL_U1_MIN_MV 1000U
#define CONTROL_U1_MAX_MV 48000U
#define CONTROL_U2_MAX_MV 20000U
#define CONTROL_I1_MAX_MA CHANNEL_B_CURRENT_LIMIT_MAX_MA
#define CONTROL_I2_MAX_MA 2000U
#define CONTROL_CURRENT_LIMIT_STEP_MA 50U
#define CONTROL_OVERHEAT_MIN_C 40U
#define CONTROL_OVERHEAT_MAX_C 70U
#define CONTROL_OVERPOWER_OFF_W 0U
#define CONTROL_OVERPOWER_MIN_W 10U
#define CONTROL_OVERPOWER_MAX_W 99U
#define CONTROL_VOLUME_MAX_PERCENT 100U

static uint16_t s_u1_mv = 12000;
static uint16_t s_i1_ma = 500;
static uint16_t s_u2_mv = 12000;
static uint16_t s_i2_ma = 500;
static bool s_overcurrent_cc = true;
static uint8_t s_overheat_c = 50U;
static uint16_t s_overpower_w = CONTROL_OVERPOWER_MAX_W;
static uint8_t s_volume_percent = 50U;
static bool s_calibration_on;
static bool s_calibration_confirm;
static bool s_calibration_confirm_ok = true;
static int64_t s_calibration_done_until_us;
static bool s_channel_a_enabled;
static bool s_channel_b_enabled;
static bool s_calibration_override;
static uint16_t s_cal_u1_mv;
static uint16_t s_cal_i1_ma;
static uint16_t s_cal_u2_mv;
static uint16_t s_cal_i2_ma;
static bool s_cal_channel_a_enabled;
static bool s_cal_channel_b_enabled;
static app_mode_t s_mode = APP_MODE_POWER_SUPPLY;
static bool s_menu_open;
static uint8_t s_menu_index = APP_MODE_POWER_SUPPLY;
static size_t s_uart_baud_index = 9U;
static size_t s_lin_baud_index = 5U;
static size_t s_rs485_baud_index = 9U;
static size_t s_can_bitrate_index = 2U;
static size_t s_current_graph_rate_index;
static size_t s_current_graph_scale_index = 2U;
static size_t s_current_graph_channel_index;
static int8_t s_lin_mask[2] = {-1, -1};
static int8_t s_can_mask[3] = {-1, -1, -1};
static int8_t s_i2c_mask[2] = {-1, -1};
static uint8_t s_selected_value = CONTROL_SELECT_NONE;
static uint8_t s_selected_digit = CONTROL_DIGIT_WHOLE;
static int32_t s_last_encoder_steps;
static bool s_settings_dirty;
static int64_t s_settings_last_change_us;
static int64_t s_last_control_activity_us;

static bool s_ui_raw;
static bool s_ui_stable;
static bool s_ui_pressed_previous;
static int64_t s_ui_last_change_us;

static bool s_encoder_button_raw;
static bool s_encoder_button_stable;
static bool s_encoder_button_pressed_previous;
static int64_t s_encoder_button_last_change_us;

static bool s_mode_button_raw;
static bool s_mode_button_stable;
static bool s_mode_button_pressed_previous;
static int64_t s_mode_button_last_change_us;

static bool s_channel_a_button_raw;
static bool s_channel_a_button_stable;
static bool s_channel_a_button_pressed_previous;
static int64_t s_channel_a_button_last_change_us;

static bool s_channel_b_button_raw;
static bool s_channel_b_button_stable;
static bool s_channel_b_button_pressed_previous;
static int64_t s_channel_b_button_last_change_us;

static const uint32_t s_serial_baud_rates[] = {
    2400U, 4800U, 9600U, 10400U, 14400U, 19200U, 20000U, 38400U, 57600U, 115200U
};

static const uint32_t s_can_bitrates[] = {
    100000U, 125000U, 250000U, 500000U, 1000000U
};

static const uint8_t s_current_graph_decimations[] = {1U, 5U, 10U};
static const uint16_t s_current_graph_scales_ma[] = {10U, 100U, 1000U, 5000U, 0U};
static const uint8_t s_current_graph_channels[] = {
    CURRENT_GRAPH_CHANNEL_A | CURRENT_GRAPH_CHANNEL_B,
    CURRENT_GRAPH_CHANNEL_A,
    CURRENT_GRAPH_CHANNEL_B
};

static char hex_mask_digit(int8_t value)
{
    if (value < 0) return '-';
    return value < 10 ? (char)('0' + value) : (char)('A' + value - 10);
}

static void format_hex_mask(const int8_t *digits, uint8_t count, char *out)
{
    for (uint8_t i = 0U; i < count; ++i) out[i] = hex_mask_digit(digits[i]);
    out[count] = '\0';
}

static uint16_t hex_mask_value(const int8_t *digits, uint8_t count)
{
    uint16_t value = 0U;
    for (uint8_t i = 0U; i < count; ++i) {
        value <<= 4U;
        if (digits[i] >= 0) value |= (uint16_t)digits[i];
    }
    return value;
}

static uint8_t hex_mask_care(const int8_t *digits, uint8_t count)
{
    uint8_t care = 0U;
    for (uint8_t i = 0U; i < count; ++i) {
        if (digits[i] >= 0) care |= (uint8_t)(1U << i);
    }
    return care;
}
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

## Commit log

2026-07-18 Refine INA ranges and current limit selection
2026-07-23 Add engineering sample interface modes
2026-07-30 Save current working firmware state
2026-07-30 Organize DOGS2 hardware mechanical and software
    [DOGS2_v1_control_panel_bom.csv, DOGS2_v1_control_panel_pick_and_place.xlsx, DOGS2_v1_power_board_bom.csv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]
2026-07-30 Add working prototype photos to README
2026-07-31 Organize schematics and known issues
2026-08-23 Document DOGS2 v1 enclosure STEP files
2026-08-23 Sync current DOGS2 firmware development
2026-09-18 Update README with additional display images
    Added images for CAN, LIN, I2C, and setting displays in the README.
2026-09-18 Fix image source for I2C sniffer display
    Updated image source for I2C sniffer display.
2026-09-18 Revise known issues and recommendations for hardware
    Updated known issues and recommendations for hardware revisions, including changes to power supply, resistor values, and capacitor placements.
2026-09-18 Update README with new top case and images
    Added top case file to parts list and updated images.
2026-09-18 Revise power channel specifications in README
    Updated specifications for power channels and features.
